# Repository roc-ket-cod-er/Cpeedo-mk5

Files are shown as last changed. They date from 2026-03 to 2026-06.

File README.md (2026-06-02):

# Cpeedo-mk5

>This project was funded by [Hack Club](https://hackclub.com/)'s Blueprint program. Hackclub is a registered, US based non-profit. Without their support, this project would not have been possible.

A _REALLY_ fancy bike speedo, designed in EasyEDA Pro and Fusion 360.



WIN_20260330_20_14_14_Pro

WIN_20260330_20_20_43_Pro

[DEMO!](https://www.youtube.com/watch/DLDQR-w_GeQ)

## Key Features

As the main goal is to measure speed, it obviously does so.

In addition, it also supports:
- a cell connection;
- anti-theft features, including using that cell connection to send the bike's position to the internet;
- a double LCD + bonus E-INK display, for live speed (etc) monitoring;
- two independent ways of measuring speed: a wheel rotation counter + GPS;
- an SD card;
- features for live navigation.

## PCB



> ⚠️ Render not up-to-date

The PCB has a 6-layer stackup to keep 2 solid ground planes, that is essential to keep the ground planes completely unbroken otherwise the antenna will be unhappy.

The stackup is:

1. Signals & Ground
2. Ground
3. Signals & Ground
4. Signals & Ground
5. Ground
6. Signals & Ground

### PCB Layers

Here's the PCB's Top layer (ground fill hidden)



Layer 3:



Layer 4:



And the bottom Layer (ground fill hidden)



> Remember, layers 2 & 5 are solid ground.

### PCB 3D Views:

Top: 



Bottom:



Bonus:



Bonus 2:



## Inspiration

Always, whenever I have been in motion, I have always wanted to know how fast I'm going. Like for some reason, you just expect to be able to know. And once you know, you can start racing yourself, start getting better, start pacing yourself, and just have more fun in general. I have made several previous editions, but in motion it has always been very hard to read the screens, and thus this time I have implemented an E-INK along with bright LCDs.

In addition, I have become increasingly paranoid about my bike being stolen, thus it would make ulitimate sense to achieve both things in one project.

## How to use

In this repository, you will find the files you need to print the case yourself, along side to get the PCB manufactured. The code, too, is present (but not finished). Thus, it is as simple as loading the code onto the board, and you should be good. The LCDs have ribbon cables, making the connection really easy, whilst the E-INK required the normal jumper wires to be hooked up.

Just put the screws into their holes, and behold! You shall have completed!

## Schematic

Here's the schematic in case you want to see it in PNG form!

SCH_Schematic1_1-Cellular_2026-02-10

SCH_Schematic1_2-GNSS - GPS_2026-02-10

SCH_Schematic1_3-STM32_2026-02-10

SCH_Schematic1_4-ESP32_2026-02-10

SCH_Schematic1_5-STM32_Sensors_2026-02-10

## BOM (PRICES MAY HAVE CHANGED: THIS IS FROM ~JAN 29 2026)

|Item |Cost (native) |Cost (USD)|Link |NOTE |TOTAL: |
|---|---|---|---|---|---|
|PCB |US$208.40+13%GST|$235.50 |JLCPCB.com |GST may not be collected. |$340.89|
|SIM card |CA$25 |$20.76 |simbase.com |Includes Adding Funds to the SIM. Taxes may reduce 13% | |
|Waveshare |US$62.47 |$62.47 |https://www.waveshare.com/catalog/product/view/id/6414/s/2.8inch-capacitive-touch-lcd/category/398/ and https://www.waveshare.com/2.9inch-e-paper-module.htm|Includes 2x LCD, + 1x E-INK + Shipping. Taxes may increase by 13%| |
|3D print |-- |$10.00 |Library |Estimate | |
|Screws |US$7.83+13% GST |$8.85 |https://www.aliexpress.com/item/1005005523283652.html |M2.5x8mm, 100pcs (minimum selected) | |
|Screw Head |US$2.94+13% GST |$3.32 |https://www.aliexpress.com/item/1005003319507557.html |T8 | |

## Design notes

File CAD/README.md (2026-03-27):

You'll find all the CAD files here.

<small> printer 1: +0.1mm 2: +0.3mm </small>

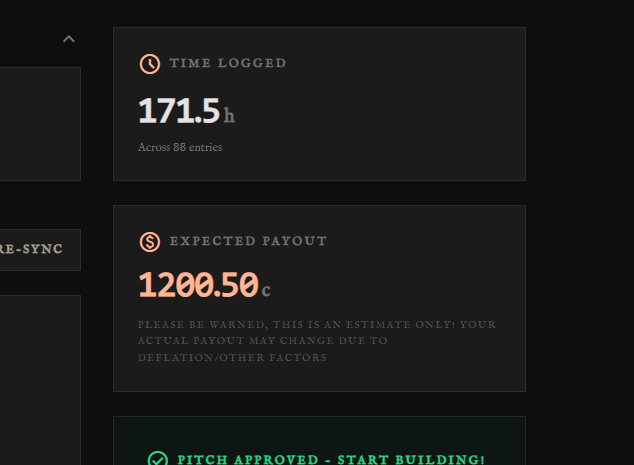
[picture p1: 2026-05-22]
assets/image.png

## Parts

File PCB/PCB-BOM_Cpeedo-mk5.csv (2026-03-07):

No. | Quantity | Comment | Designator | Footprint | Value | Manufacturer Part | Manufacturer | Supplier Part | Supplier
1 | 2 | BH-18650-A1AJ006 | BT1,BT2 | BAT-TH_BH-18650-A1AJ006 |  | BH-18650-A1AJ006 | MYOUNG(美阳) | C5290175 | LCSC
2 | 1 | 2.7pF | C1 | C0402 | 2.7pF | 0402CG2R7C500NT | FH(风华) | C1561 | LCSC
3 | 1 | 0.5pF | C2 | C0402 | 0.5pF | 0402CG0R5B500NT | FH(风华) | C285052 | LCSC
4 | 29 | 100nF | C3,C4,C5,C8,C10,C11,C12,C13,C14,C15,C20,C21,C31,C33,C34,C35,C38,C40,C41,C42,C43,C46,C52,C53,C54,C55,C57,C59,C60 | C0402 | 100nF | CL05B104KB54PNC | SAMSUNG(三星) | C307331 | LCSC
5 | 2 | 2.2uF | C6,C7 | C0603 | 2.2uF | CL10A225KO8NNNC | SAMSUNG(三星) | C23630 | LCSC
6 | 4 | 10uF | C9,C26,C27,C45 | C0603 | 10uF | CL10A106KP8NNNC | SAMSUNG(三星) | C19702 | LCSC
7 | 5 | 1uF | C16,C39,C49,C51,C56 | C0402 | 1uF | CL05A105KA5NQNC | SAMSUNG(三星) | C52923 | LCSC
8 | 4 | 100uF | C17,C18,C19,C32 | C1206 | 100uF | CL31A107MQHNNNE | SAMSUNG(三星) | C15008 | LCSC
9 | 2 | 10uF | C22,C36 | C0402 | 10uF | CL05A106MQ5NUNC | SAMSUNG(三星) | C15525 | LCSC
10 | 1 | 4.7uF | C23 | C0402 | 4.7uF | CL05A475MP5NRNC | SAMSUNG(三星) | C23733 | LCSC
11 | 2 | 15pF | C24,C25 | C0603 | 15pF | CL10C150JB8NNNC | SAMSUNG(三星) | C1644 | LCSC
12 | 5 | 22uF | C28,C29,C30,C37,C44 | C0603 | 22uF | CL10A226MQ8NRNC | SAMSUNG(三星) | C59461 | LCSC
13 | 1 | 2.2uF | C58 | C0402 | 2.2uF | CL05A225MQ5NSNC | SAMSUNG(三星) | C12530 | LCSC
14 | 1 | TF PUSH | CARD1 | TF-SMD_TF-PUSH |  | TF PUSH | SHOU HAN(首韩) | C393941 | LCSC
15 | 1 | SRV05-4 | D1 | SOT-23-6_L2.9-W1.6-P0.95-LS2.8-BL-1 |  | SRV05-4 | R+O(宏嘉诚) | C7420376 | LCSC
16 | 1 | PZ254V-11-05P | H2 | HDR-TH_5P-P2.54-V-M |  | PZ254V-11-05P | XFCN(兴飞) | C492404 | LCSC
17 | 3 | AFC07-S18FCC-00 | JP1,JP2,JP3 | FPC-SMD_AFC07-S18FCC-00 |  | AFC07-S18FCC-00 | JS(钜硕电子) | C11054 | LCSC
18 | 1 | 1462000001 | L1 | ANT-SMD_L40.0-W5.0_1462000001 |  | 1462000001 | MOLEX | C3284456 | LCSC
19 | 1 | 7.5nH | L2 | IND-SMD_L1.2-W0.6 | 7.5nH | SCW1005C7N5JST | Sunltech(顺磁) | C330848 | LCSC
20 | 1 | 2.2uH | L4 | L1008 | 2.2uH | DFE252010F-2R2M=P2 | muRata(村田) | C488330 | LCSC
21 | 2 | BLM15AX102SN1D | L5,L6 | L0402 |  | BLM15AX102SN1D | muRata(村田) | C85815 | LCSC
22 | 1 | KT-0603R | LED1 | LED0603-RD |  | KT-0603R | KENTO | C2286 | LCSC
23 | 3 | KT-0805G | LED3,LED4,LED5 | LED0805-R-RD |  | KT-0805G | KENTO | C2297 | LCSC
24 | 3 | BSS138 | Q1,Q2,Q3 | SOT-23-3_L2.9-W1.6-P1.90-LS2.8-BR |  | BSS138 | onsemi(安森美) | C52895 | LCSC
25 | 3 | 22Ω | R1,R2,R3 | R0402 | 22Ω | 0402WGF220JTCE | UNI-ROYAL(厚声) | C25092 | LCSC
26 | 4 | 5.1kΩ | R6,R7,R8,R9 | R0402 | 5.1kΩ | 0402WGF5101TCE | UNI-ROYAL(厚声) | C25905 | LCSC
27 | 16 | 10kΩ | R11,R14,R17,R25,R26,R27,R28,R29,R30,R31,R32,R33,R34,R35,R36,R44 | R0402 | 10kΩ | 0402WGF1002TCE | UNI-ROYAL(厚声) | C25744 | LCSC
28 | 7 | 680Ω | R12,R13,R15,R16,R18,R41,R42 | R0603 | 680Ω | 0603WAF6800T5E | UNI-ROYAL(厚声) | C23228 | LCSC
29 | 1 | 1kΩ | R19 | R0603 | 1kΩ | 0603WAF1001T5E | UNI-ROYAL(厚声) | C21190 | LCSC
30 | 1 | 100kΩ | R20 | R0402 | 100kΩ | 0402WGF1003TCE | UNI-ROYAL(厚声) | C25741 | LCSC
31 | 1 | 33Ω | R37 | R0402 | 33Ω | 0402WGF330JTCE | UNI-ROYAL(厚声) | C25105 | LCSC
32 | 1 | 36.5kΩ | R38 | R0603 | 36.5kΩ | 0603WAF3652T5E | UNI-ROYAL(厚声) | C23029 | LCSC
33 | 1 | 20mΩ | R43 | RES-SMD_L6.4-W3.2-R2512 | 20mΩ | RE2512F3R020 | JIERR(捷而瑞) | C46961755 | LCSC
34 | 4 | TS-1088-AR02016 | SW1,SW2,SW3,SW4 | SW-SMD_L3.9-W3.0-P4.45 |  | TS-1088-AR02016 | XUNPU(讯普) | C720477 | LCSC
35 | 1 | SK12D07VG4 | SW5 | SW-TH_SK12D07VG4-1 |  | SK12D07VG4 | HanElectricity(瀚源) | C22435621 | LCSC
36 | 1 | K3-1204D | SW6 | SW-TH_K3-1204D |  | K3-1204D | 韩国韩荣 | C145861 | LCSC
37 | 1 | SIM7080G | U1 | LCC-SMD_SIM7080G |  | SIM7080G | SIMCOM(芯讯通无线科技) | C2943992 | LCSC
38 | 1 | NANO SIM XG6P H1.35 | U2 | SIM-SMD_NANO-SIM-XG6P-H1.35 |  | NANO SIM XG6P H1.35 | SHOU HAN(首韩) | C7529386 | LCSC
39 | 1 | STM32U575VGT6 | U3 | LQFP-100_L14.0-W14.0-P0.50-LS16.0-BL |  | STM32U575VGT6 | ST(意法半导体) | C5270988 | LCSC
40 | 1 | ESP32-S3-WROOM-1-N16R8 | U4 | WIRELM-SMD_ESP32-S3-WROOM-1 |  | ESP32-S3-WROOM-1-N16R8 | ESPRESSIF(乐鑫) | C2913202 | LCSC
41 | 1 | TXB0108RGYR | U5 | VQFN-20_L4.5-W3.5-P0.50-BL-EP |  | TXB0108RGYR | TI(德州仪器) | C194701 | LCSC
42 | 1 | L80RE-M37 | U6 | GPSM-SMD_12P-L16.0-W16.0-P2.54-BL |  | L80RE-M37 | Quectel(移远) | C3029061 | LCSC
43 | 1 | ABM8-272-T3 | U7 | CRYSTAL-SMD_4P-L3.2-W2.5-BL |  | ABM8-272-T3 | ABRACON | C20625731 | LCSC
44 | 1 | TPS63021DSJR | U8 | VSON-14_L4.0-W3.0-P0.50-BL-EP_TI_DSJ |  | TPS63021DSJR | TI(德州仪器) | C202140 | LCSC
45 | 1 | 1.5uH | U9 | IND-SMD_L3.0-W3.0_FTC303020D | 1.5uH | FTC303020D1R5MBCA | cjiang(长江微电) | C7423317 | LCSC
46 | 1 | INA226AIDGSR | U10 | MSOP-10_L3.0-W3.0-P0.50-LS5.0-BL |  | INA226AIDGSR | TI(德州仪器) | C49851 | LCSC
47 | 1 | TPS63900DSKR | U11 | WSON-10_L2.5-W2.5-W0.50-TL-EP |  | TPS63900DSKR | TI(德州仪器) | C1518762 | LCSC
48 | 1 | ICM-42688-PC | U12 | LGA-14_L3.0-W2.5-P0.50-TL |  | ICM-42688-PC | Tokmas(托克马斯) | C48586483 | LCSC
49 | 1 | BMM150 | U13 | WLCSP-12_L1.6-W1.6_BMM150 |  | BMM150 | Bosch(博世) | C171681 | LCSC
50 | 1 | 2541WR-08P | U16 | HDR-TH_8P-P2.54-H-M-W10.4 |  | 2541WR-08P | HanElectricity(瀚源) | C5383100 | LCSC
51 | 2 | KF350R-3.5-2P | U17,U19 | CONN-TH_P3.50_KF396R-3.5-2P |  | KF350R-3.5-2P | KEFA(科发) | C474896 | LCSC
52 | 1 | KF350R-3.5-3P | U18 | CONN-TH_3P-P3.50_KF396R-3.5-3P |  | KF350R-3.5-3P | KEFA(科发) | C474897 | LCSC
53 | 2 | TYPE-C 16PIN 2MD(073) | USB1,USB2 | USB-C-SMD_TYPE-C-6PIN-2MD-073 |  | TYPE-C 16PIN 2MD(073) | SHOU HAN(首韩) | C2765186 | LCSC

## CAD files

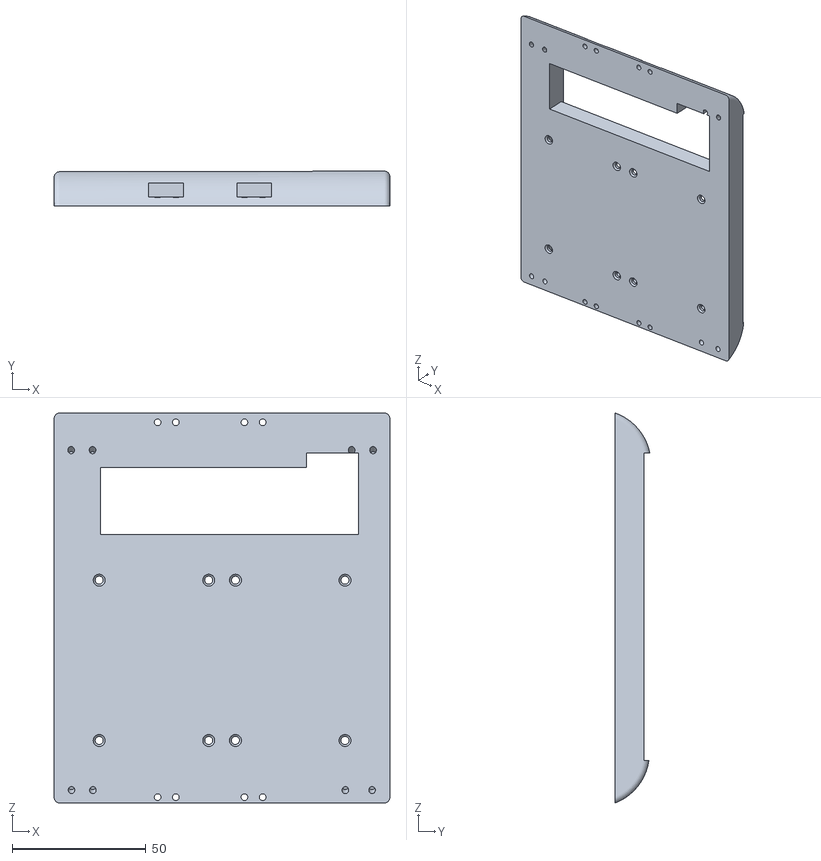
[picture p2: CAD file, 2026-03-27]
CAD/Main Truss.stl
125.7 x 13.0 x 146.0

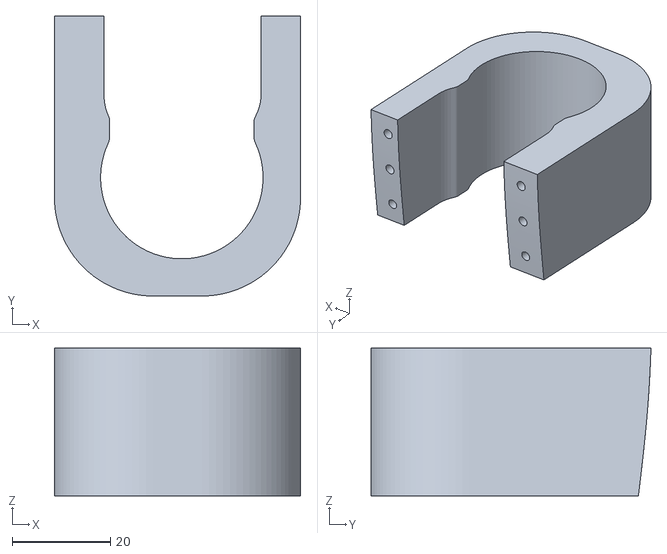
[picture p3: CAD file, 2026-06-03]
CAD/Bike-Mount.stl
50.0 x 56.9 x 30.0

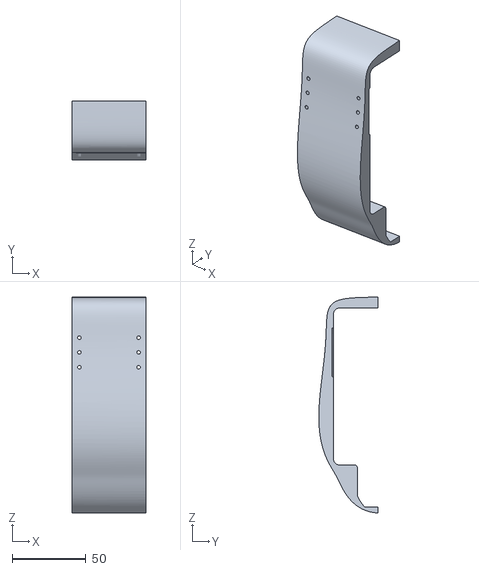
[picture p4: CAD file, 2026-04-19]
CAD/Battery.stl
50.0 x 40.1 x 146.0

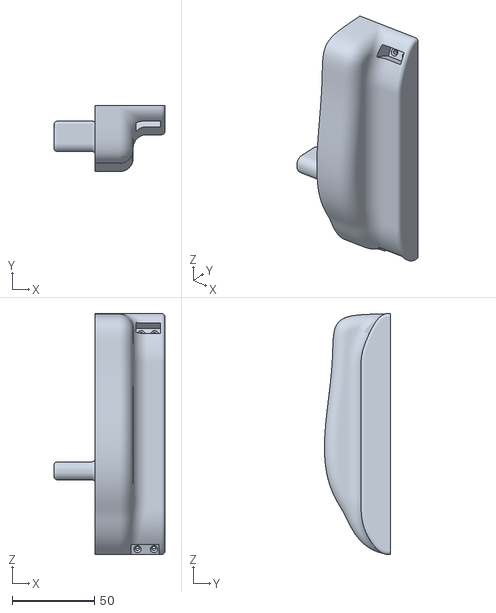
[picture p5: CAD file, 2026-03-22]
CAD/Right-Bottom.stl
67.3 x 40.1 x 146.1

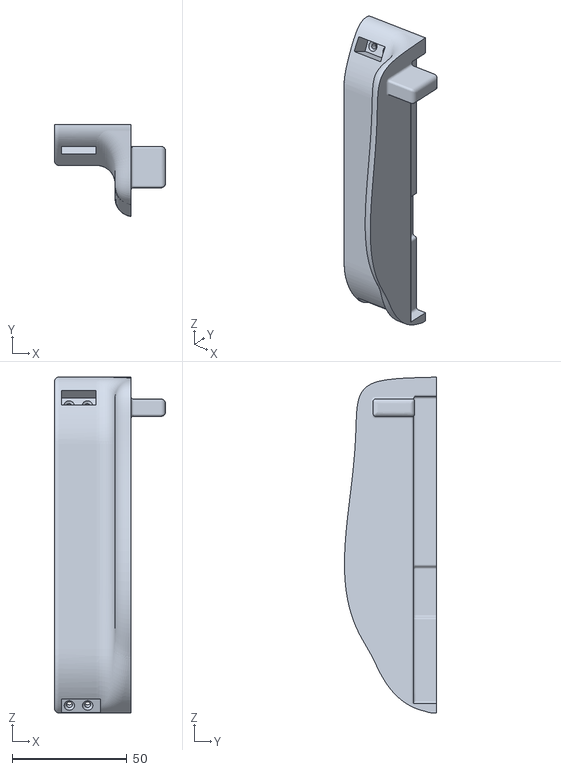
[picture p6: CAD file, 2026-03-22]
CAD/Left-Bottom.stl
48.4 x 40.0 x 146.1

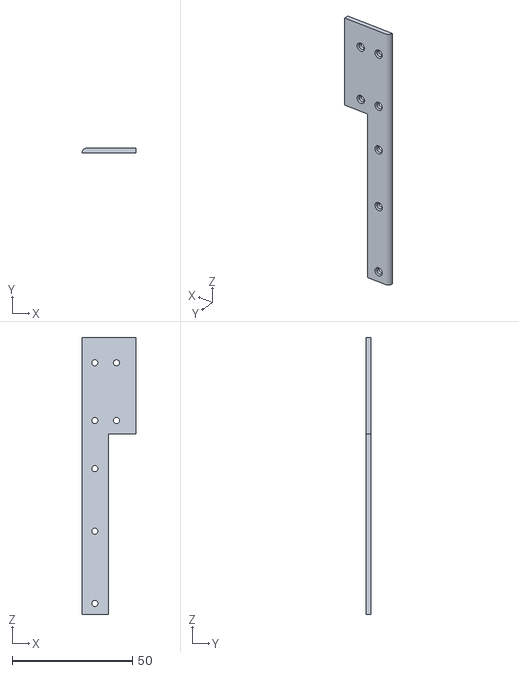
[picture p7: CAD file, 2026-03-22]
CAD/Left Mount.stl
22.5 x 2.00 x 115.1

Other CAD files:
CAD/Cpeedo-mk5.step
CAD/Right Mount.stl
CAD/Cpeedo-mk5.f3z

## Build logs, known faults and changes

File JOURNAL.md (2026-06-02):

---
title: "The Ultimate Bike Odometer"
author: "Madhav Garg"
description: "The best bike odometer you'll ever see"
created_at: "2026-02-20"
---

<!--
  This journal is auto generated by Hack Club Blueprint.
-->

# 2/25/2026 - Bought some stuff & checks and stuff  

_Time spent: 0.6h_  

Mostly just double-triple checked stuff and bought it!



So yeah, the thing is that one of the things was from a blocked category, so I had like get @jay to unblock it, but then he had to re block it, but the problem was I had 2 orders, so he had to do that twice...

Well anyways I probably did some other stuff but I forgot it all so...  

# 2/27/2026 6 PM - Rerouted a bunch of the bottom layer  

_Time spent: 1.9h_  

Basically, I want to put art onto the bottom layer, and thus I rerouted many signals so that the bottom is just mostly ground, on which its far safer to remove the soldermask



As you can see, there's only a bit of routing on the densest part of the board, but other than that its all gone!



Now time to actually get the art going!

By the way, most places were relatively easy, just switching the trace layer, but others required quite a bit of change.



I also tidied up this corridor so that the majority is in line with itself and thus doesn't affect the ground stitching around the ground plane too much.  

# 2/27/2026 9:36 PM - Artwork  

_Time spent: 0.7h_  

I added a bunch of new art, fully custom (except for the hackclub logo)

It took soooo long because in the beginning I was going to make a single PNG and import it, but I just ended up importing individual files and putting them in the right spot. It was just too hard to have one.





I'm going to clean up the backside a bit, but first I have to move all the Part-Identifiers so they are legible over this new silkscreen



# 2/27/2026 9:55 PM - Designators  

_Time spent: 0.4h_  

I moved all the designators on the top side so that they are readable with the new wavy lines. The backside will be done tomorrow, when I redo that silkscreen to not conflict with the hackclub logo.



Anyways, there just was this one spot with the microSD card where it was tough, but most of the other places were easy enough



# 3/2/2026 - Artwork & Suture/Stiching Vias  

_Time spent: 2.6h_  



First things first, I quickly fixed the artwork on the back side so that the hackclub logo wouldn't have lines going through it



However, on the front side I got feed back that the silkscreen was just a bit too much, especially with the ENIG art, and thus I removed it, even though I had moved all the designators...



 ### The hard part

So that was all good, just a bit of easy artwork. But, the stiching vias were _really_ bad this time, as for some reason the DRC was allowing the vias to be placed too close to each other, and then flagging them. So, I had to go through and remove each violating via by hand... (Some 50~60 vias)



> <small> btw my board now has 3000+ vias!! </small>

Anyways, after that, there was the headers for the speed and 2 IO (buttons, etc) that were sort of conflicting with the battery, so I re-arranged them.



 ### Debug Header

Reddit said that I should add the NRST pin broken out on the debug header, so that's what I did.



Required some wiring, including some on the bottom layer. (Which is my mostly empty one)  

# 3/3/2026 - Added Another FPC Connector  

_Time spent: 4.3h_  

This is basically just so that if in the future I want to have it connect to a daughter board, it will be able actually communicate. Because I didn't have access to STM32CUBEMX, I had to look through the datasheet to find out which pins (of the remaining) were the most capable so that I could actually use them. I settled on this setup:



> Note: STM/ESP32_SCK is actually PA1

So now, I was left with the daunting task of finding the ideal order (shown above) so that it would actually be possible to route. On my 5th revision, I found that.

---

Now to actually wire this monster up



As you can see, the majority of the lines look alr, and I might actually just change the two weird ones (on the bottom).

The biggest problem, however, is the fact that this is already the most dense part of the board, where the four layers are most full, so wiring an addition ~16 lines is not going to be fun. Thankfully, if absolutely need be, I can always use inner 4, which is supposed to be GND only...

 #### Some Time Later

Ok! I think I've settled on this setup for the pins:





Now time to route this all...

 ### ~~Routing~~ More double checking!

Here's (hopefully) the final thing.





_Now_ it's time for some routing

 ### Routing

(some time later)

Ok so here's what I have!



This is one heck of a dense board, with all four layers being quite well used: (L3,L4,L6)







Not gonna lie, but that was quite a bit easier than I was expecting. I did end up changing a bit of the schematic, so that it would actually be nicely usable, so here it is!



(Mostly just switching around a few pins to avoid loops)

Yeah well that was a full days work! Proud of what I got done.

Oh yeah, btw re-added the suture vias (the ones that connect between layers)

~~ALSO I NOTICED THAT ALL MY JOURNALS FROM THE PAST DAY ARE ALL GONE?????????????????????????????? Like 10 hrs of work dissapeared!!~~ Just a glitch  

# 3/4/2026 - Tested (& Received) E-INK DISPLAY!!!  

_Time spent: 2.3h_  

Firstly, I received the displays!!!!!

WIN_20260304_18_15_56_ProWIN_20260304_18_15_49_ProWIN_20260304_18_15_42_ProWIN_20260304_18_15_53_Pro

WIN_20260304_18_10_47_Pro

That last one might have looked weird ... that's my E-INK!

It was actually a pain to get it working. First, I connected it to my rpi Pico's wrong 3V3, so it wasn't getting power, then [the library](https://github.com/rdagger/MicroPython-2.9-inch-ePaper-Library/tree/master) was really weird and glitching out. So, I changed my library to Waveshare's official one, however I messed up and installed the 2.13 inch display one, not the [2.9 inch one](https://github.com/waveshareteam/Pico_ePaper_Code/blob/main/python/Pico_ePaper-2.9.py), so again it didn't work.

In between, I had messed up with which pins were SCK and MOSI, and kept getting the `Bad Pin` error, so that definitely wasn't nice.

All in all, it's really great it worked, but it took too much effort ... Hoping the LCDs are easier!  

# 3/10/2026 - LCD & E-INKing  

_Time spent: 4.5h_  

Alr, so, believe it or not, the LCD just worked first try!!!!!!

It was lowk so easy, took like 10 mins to wire it up (and double check and stuff) then I just found the official code and it just worked!!

While I'm at it, the screws also arrived, and hey, they fit!

And now the really time consuming part. E-INK custom text scaling!

WIN_20260308_16_11_53_Pro

Just so you know, I did, in fact, get it to work, but the thing is I just thought it would be as simple as just copying the LCD text scaler function over, and it would just work.

ye ofc it wasn't

But first, before I get to that part, I just wanted to talk about how I really goofed up in reading the E-INK code, so previously it would just drive the E-INK when the `vertical_write()` calls would come in, and not for the `horizontal_write()`, and I was really wondering why, and it turns out that I didn't change the SPI pins on the `Horizontal` class, just on the `Vertical` class.

Quick fix, just changed that, (but not so quick to find it, ofc) and now instead of waiting 10+ seconds for the screen to initialize, it just does so within a second!

So yeah, now that I had got that to initialize far faster (a problem I had been observing for quite a while, but was unsure of why), I decided that if my speedo was gonna be readable in bright sunlight, it would make most sense for the E-INK to be able to display speed, too.

Since, I needed it to be visible at a bit of a distance while shaking, I decided that I should find out how to make the text big enough to be readable. Hence, the problem

So I briefly touched upon how the LCD has a scaler, which it does, but the thing is that it's designed for a different setup, with colour displays and stuff.

So, I went looking online and I found [this.](https://github.com/orgs/micropython/discussions/16382)

Basically, it does the exact same thing, but somehow works (after much modding)

"What modding," you ask?

Well firstly, I had to actually _understand_ the code, and here's a rundown of what it does.

Put simply, it take micropython's framebuffer's built in font, and then reads it, by putting it into a new framebuffer and reading every pixel.

Then, it takes those readings, and draws rectangles that are the scale. So, if we were drawing to a 2x scale, it would draw the rectangles to be 2x2 pixels, instead of the default 1.

However, to do that, you must actually first make the framebuffer, which apparently can just be done by this:

>me forgetting and searching my code

ok so yeah its actually really simple, just go 

`temp_fb = framebuf.FrameBuffer(temp_buf, width, height, framebuf.MONO_VLSB)`

>(if you have imported the frambuf library)

The problem just was that the code there used something different, and I have basically never used framebuf.

Alright so once that is there, there is still the fact that normally, 0x00 is black, and 0xff is white right?

Well for some reason that was flipped

I was writing 0x00, and I was getting white, while 0xff was giving me black...

(I now know that that was just because of the fact that the temporary framebuf [the one with the micropython default fonts] was the right one, but then it was being flipped by a stupid piece of [my own] code.)

By the way, writing these huge essays takes sooo long



Anyways, yeah that's about it! Now I have the text scaler!

Also, there is this really stupid thing that even if I clear the buffer, running `buffer.Clear(0xff)`, it doesn't really, and I still have to run `buffer.fill(0xff)`

Oh well, also two more notes:

1. THE PCB IS DONE PRODUCTION!!! (Now all I have to do is wait for them to assemble it!)
2. I noticed that I can arrange the screens in a better way that should look better, And thus I'm thinking of completely remodling my entire thing... I should get that done real quick so that its done by the time the PCB arrives and I can just go print it and worry about debugging my PCB

 ### NOTE: As you can see, this is a really long journal, and really long journals take a tonne of time to get done on their own ...  

# 3/11/2026 - Re-3D modelling  

_Time spent: 2.0h_  

I finally came around to do it, and so here it is!

Not nearly (or even close to being) done...







So yeah, white is e-ink, screens are obviously screens, pcb is also obviously the PCB, and the beige is the main case. The orange is the mounting pieces that are going to be used to mount the E-INK on, as it doesn't have useful screw holes.

However, it does have a pin header, that has this hole for it:



(The center is also shallower as there is the E-INK driving circuitry on the back)

Not much more to say, other then the fact that I'm worried about the GPS performance, as it has the batteries right under it, even though there is supposed to be a keepout. In addition, the E-INK is also quite close to it, but I think it should most likely be alright.

I'm really proud of the fact that I was able to finish this so quickly, taking just about two hours.

Next time, my plan is to add the main PCB mount, and bother with the screws.

I also will have to figure out the bike mount clips, but I think I'll do that part and the battery mount section later, after I get this part printed out and tested.  

# 3/13/2026 - Pretty Much Finished 3D Model  

_Time spent: 4.5h_  

So yeah, I Pretty Much Finished 3D Model.



All I really need to add know is the bike mount, and the screw holes to hold everything together!

So, pretty much, all I worked on was the back part.



This part will hold the PCB, in such a way that, with screw holes, will be able to also accommodated the batteries in a way that they can be removed for charging.



Where the more turquoise blue is is where the batteries are, and that is also where the thing will come off for when I want to recharge the batteries.

This might not seem like a lot, but compared to my last render, this whole workflow just _happened_ much faster, and I'm actually quite proud.

And this is even after me having to redo much of my work, as V18 got deleted, so I had to go back to V17, and there was this problem:



Even though it's just the inside, I wanted that to also look nice, so that's why I wanted to fix that up, but the normal way I would do it in fusion 360 didn't quite work as it would keep say computation error. Thus, I had to go google it, and it wasn't of much help either. So, I just tended up deleting that bad part, and just extending the sides all the way to the cover that area.





Here's what the inside looks like:



Again, where its more turquoise is the battery area, whereas the bluer area is the other mounting part.

Just reworked some stuff for tolerances, so here it is:

PCB CASE:







FULL:







# 3/14/2026 - Worked On 3D Model: Bike Mount  

_Time spent: 1.8h_  

I speedran the bike mount, the place where the speedo will mount to the bike



This is my first try at clip-on 3D prints, as the hole is a millimetre or two too small, so it's gonna be under a nice amount of pressure and thus gonna have a tonne of friction.





It's also designed to be screwed on right here to connect to the main body.

It should be noted that everything is a touch too small to make sure there is sufficient friction.

It is also nice that the bar is vertical,



So that the friction only has to prevent it from rotating sideways, not up and down.

I'm still a bit confused on how to connect it and everything, but its gonna probably be that the mount screws onto the back battery plate, which then has screws to the main body that are gonna have to be taken off everytime the batteries need to be charged.

Now all I need to do is add the screw holes, and I should be done!  

# 3/15/2026 - Added:   S O   M A N Y   S C R E W   H O L E S  

_Time spent: 3.7h_  

yep, that's what I did.

 ### Firstly, there is the top side:



A _TONNNE_ of screw holes. It should be noted that the screw hold on the right side, bottom left of the box, is just there for show.

There is nothing for it to dig into.



 ### Back Side:

Here it is:





This all required me to cut out the bottom plate so that the screws can fit, as there is really only one screw type that is going to be used in all the holes.

 ### The hard part: PCB Mount

When looking here, its hard to see:



But if I hide the PCB:



Not only did the hole alignment take so long, but also the fillets took just s o . l o n g .

s o o o o o o o o o . l o n g .

They kept on giving me errors, and all that nonsense. At least I didn't have to chamfer these holes.

 ### Chamfering

If you looked really closely, you'd see the chamfering:



This is so that the screw can sit flat, and this too took so long, as google just couldn't tell me how to chamfer. (It was really simple once I found it)

Now all I need to do is the back mount!



PCB should be arriving tomorow!

bonus:

(main truss, looks so tuff)









# 3/16/2026 - PCBs ARRIVED: GOT THE LED TO BLINK!!!!!  

_Time spent: 1.7h_  

Yep. Believe it or not, the naysayers and the haters have been shut down for good.

Those little-lings will now not be able to call me "one-who-cannot-program-an-stm32" as that is just what I did.

So it was a real mess trying to get everything to work, but really all I had to do was just ask @tty7 to tell me why it wasn't working, and all he had to do was tell me that you actually have to press the "boot" button for picky Ms. Windows to detect the STM32.

From there it was ~~smooth sailing!~~ more pain...

So now I had to figure out how to program it. @tty7 wasn't gonna be available for an hour, so instead I spent that hour in the googles. Firstly, I looked for a way to program it. Arduino IDE maybe? yeah no that didn't work

So I came back and found [this epic video detailing exactly how to program the STM32 by USB](https://www.youtube.com/watch?v=VlCYI2U-qyM)

and From _there_ it was ~~smooth sailing!~~ more pain...

yeah this time I had to like actually find out how the main things work, and considering the include the `main()` functions box was unchecked, that must have been a real nice, easy, time.

So once I rechecked that box, added these two lines of code:



and then flashed it like how the video said, and it just worked!

Lowk so happy

oh yeah forgot to say, my PCBs ARRIVED!!!!!

lowk so cool. I need to solder the ESP32 on, find libraries for my stuff and maybe not even use this, repent for making a _micropython_ library for text scaling, and yeah.

Also, I'm paranoid I'm going to plug the battery in the wrong way and cook my stuff, so there's that. Haven't yet soldered on the battery holder, so once in a while power just cuts out. (the USBs don't provide my board with power)  

# 3/18/2026 - Got CELL TO WORK & soldered esp32  

_Time spent: 7.8h_  

Most importantly, I got the CELL STUFF TO WORK!!!



But anyways, the story

 ### Soldering

Firstly, there was the soldering.

Preparations alone took me like 30~45 minutes, as I had to find a space, clear it, and then the difficult part: find the components.

So, the thing is, the ESP32s sort of disappeared, but were actually where I though they were all along, so minus 10 minutes (yes, I know, I'm slow)

Then, the same thing happened with the Flux. Like it shouldn't be so hard to find a big tube of orange goo, when I don't own anything orange.

<small>
>(idk where it was now, and i lowk managed to lose it _again_ ... nvm found it)
</small>

Anyways, then the flux tube wouldn't open.

At first, I thought that I stored it wrong or something, but no it was alright. So then _why would it not just open_?

because it was too cold

All I had to do was just add some heat, and voila it just opened

THEN, on the first board I guess I messed up and put too little flux or something, but when I soldered the ESP32, it just didn't go very well, and uhh i also tried pre-adding solder to the pads and that ended up just desoldering the decoupling capacitors.



Thankfully, the second set of stuff went much easier, and I just powered it and connected it and it just worked!!!!

The default firmware on these chips is cooked, so that's why I had to quickly flash new firmware before windows gave me a headache of complaints.

Alls well, though, and it just worked.

Next up, the switch.

 ### Stupid Switches

Don't you just love alliteration.

Anyways, normally, when you slide the switch to the right, the right and center short, whilst the left two are not. Right????????

Nope. Not on this switch. That took me _sooooo_ long to figure out why it wasn't getting power (the cell chip)

It took me so long to get the wits to actually bother to check the resistance and its behaviour... :(

Well, whatever, it works it works.

 ### Coding & Cell

Ok, now the sad part.

When I was testing the stuff for voltage, I accidentally shorted the outside of the antenna to the VBAT pin, and who would think, the outside is connected to GROUND.

So well, what happens when you short the pins like that? Smoke. Lots of it. Well I was about to give up at that, but I thought: "hmmmm what if I try and plug it in anyways?"

So I did.

Plugged the battery in, and the STM32 turned on (it was programmed just to blink its LED)

Turned on the switch for the ESP32. 

And.

IT ALSO TURNED ON!!!!

So basically, as far as I could tell, all was well.

But there was still the CELL CHIP. I knew for a fact that it was a very sensitive chip, so I was just given up on that and willing to accept a functional ESP32/STM32 devboard.

So, when I first failed to turn on the Cell Chip, I was sort of just confirming my suspicion. But, against all odds (after 30+ minutes) I decided to consult chatGPT.

I don't normally ever use it, as it hallucinates random code more often than useful code.

But it actually worked.



<small> my shock ^^^ </small>

Anyways, that was absolutely great news. Despite smoke coming from my board, it just worked.

Then, I just fumbled with chatGPT to give me AT commands, and it, again, just worked.



However, there was this small problem. I was getting signals once in a while. However, thankfully, it was just warming up, and now it connects reliably.

The next problem was actually getting Adafruit IO to receive data, and that was done by just taking a look at what AT commands Waveshare uses on there SIM7080G boards, and copying them. (More like adapting them to my framework, as they were written for the Raspberry Pi)

And yeah, in short, that's all I had to do. I sort of glazed over the _hours_ of pain that it took to get it working with the SIM module, but hey, all's well that ends well.

I also had the horrifying thought of giving up hardware. Super happy I didn't!!  

# 3/20/2026 - Cleaning Up Basic Code & HTTP SADNESS  

_Time spent: 5.1h_  

So I spent an hour or two cleaning up my code, so basically it's like _clean_ and working well.

Whereas my previous code was comprised of functions and AT commands every where, my current setup is having a proper function, with some comments, but not very many.

```python
def connect_to_cell(server, url=''):
    global connected
    if not powered_on():
        power_on()
    
    send_at('AT+SMDISC') #DISCONNECT FROM ADAFRUIT IO
    send_at('AT+SHDISC')  #DISCONNECT FROM HTTP
    
    #send_at('AT+CGDCONT=1,"IP","simbase"')
    
    while "99,99" in send_at("AT+CSQ", wait=.1):		# signal
        sleep(0.3)=

    while "NO SERVICE" in send_at("AT+CPSI?", wait=.1):
        send_at("AT+CSQ", wait=.1)
        sleep(0.3)

    send_at("AT+CGACT?", wait=.1)		#active?
    send_at('AT+CGDCONT?', wait=.1)		#ip & stuff
    send_at('AT+CGPADDR=1', wait=.1)		#connect to wifi
    
    send_at('AT+CNACT=0,1', wait=.1)
    send_at('AT+CACID=0', wait=.1)

    if server in ['io', 'adafruit', 'mqtt']:
        send_at('AT+SMCONF="URL","io.adafruit.com",1883', wait=.1)
        send_at('AT+SMCONF="CLIENTID","esp32-sim7080g"', wait=.1)
        send_at('AT+SMCONF="USERNAME","space_coder"', wait=.1)
        send_at('AT+SMCONF="PASSWORD","WHY THE HECK ARE YOU TRYING TO SEE MY PASSWORD????????"', wait=.1)
        send_at('AT+SMCONN', 1)
    if server in 'https':
        send_at('AT+SHCONF="BODYLEN",1024', wait=.1)
        send_at('AT+SHCONF="HEADERLEN",350', wait=.1)
        send_at(f'AT+SHCONF="URL","{url}"', wait=.1)
        send_at('AT+SHCONN', 5)

    connected = True
```

(cleaned up version)

That, above, is my connect function, and as you can see in addition to cleaning up the code, I also figured out how to speed it up so that it works well. Whereas my previous function would take well over 15 seconds, some two seconds per command, now it takes about 3 seconds to connect to Adafruit IO, or about 7 seconds to connect to connect to a webpage (I'll get to this later).

I also set it up with the DTS and RTS commands, so that if I want higher bauds, in the MHz range, I can.

Furthermore, I re-setup the UART, as previously there was a built in slowing function, adding about 1 second to every read.

 ### HTTPS

~~So this part was just like the others~~

I wish.

The other cell features were actually pretty easy, but this time chatGPT started overly hallucinating, so that is why it took _so_ long.

Firstly, there was the pinging. To get it to send a ping, I had to find a good source, as GPT wasn't working. [This one](https://onomondo.com/blog/how-to-ping-your-modem-using-at-commands/) had a good chunk of the stuff I needed, but it was a bit confusing, as the APN was different on their page. All in all, the pings were quite easy, and then there was the actual reading part.

Reading is as simple as sending `send_at('AT+SHREQ="/",1', 10)` and then `send_at('AT+SHREAD=0,528', 10)`

But the connection part is a whole other mess.

So as you can see, my current connection function asks whether I want to connect to IO or HTTP, and that's not because of speed or anything. That's because 90% of the time it cannot connect to both. So the correct course of action would have been to disconnect from the IO, as I now do, and then connect to the HTTP, however I didn't know that, so I was just like stuck and wondering why my connection code wasn't working, but the example did.

Once I figured that out, it was quite easy, really. Just make sure to disconnect, and all should be well.

 ### The Pain

So, I decided that I was going to clump the functions and clean them up so that it won't waste time and data connecting to the MQTT if I wanted the HTTP, and vice versa. So, I put the code in and it just didn't work. I debugged it for a solid _hour_ and I finally found the problem. I had commented out the lines of code that told my modem how much of a buffer to assign to the read function, and voilà, nono functioning.


Uncommenting those lines pretty much fixed the entire problem, and yeah.

 ### 3D printing

I went to the library today to see if they had a printer open, and, even in this weather (its raining/cold), there was not a printer (out of 2) that was open.

Also, I'd just like to note: picture are going to be hard as I don't have much to show, other than code, and I don't have a camera.

<small> p.s. This journal alone took me 17 minutes of locking in/focusing.  

# 3/21/2026 8 PM - Finished 3D Model  

_Time spent: 2.0h_  

Yep!

I fixed up tolerances, and added the final screw holes!




That means 6 holes here (3 both sides)


which connect to the battery clip here:





Which connects to the body here:






This side didn't have enough space, so the chamfer and screw hole actually goes a bit onto the sides:





I also fixed up the display holes so that they would actually hold the screw, and not just let it slide right through.

  

# 3/21/2026 9 PM - Got 2x 3D printed parts  

_Time spent: 0.1h_  

I went to the library and just sat there for ~30 mins waiting for my print. Gonna have a lot more of that...

Anyways, I just barely missed my bus home, so I had to wait an extra 30 mins :(

WIN_20260321_21_58_30_Pro

I'm not adding the 2hrs.  

# 3/21/2026 10 PM - Got Screens To Work  

_Time spent: 1.8h_  

So yeah, basically I got them to work!

WIN_20260321_21_50_21_ProWIN_20260321_21_50_15_Pro
WIN_20260321_21_50_29_Pro
WIN_20260321_21_50_35_Pro

So, I had already got the screen to work, but that was by connecting them to my rpi Pico, which apparently has more RAM than my ESP32 (not PSRAM, RAM)

So I got this lovely error:

```
MemoryError: memory allocation failed, allocating 153600 bytes
```

 ### New Library

Ok, well the official waveshare one didn't work, so I thought of just googling the chip, the ST7789T3. And right there, I found the [ST7789](https://github.com/russhughes/st7789_mpy) Library, something that I have even used before!

The thing is, I'd forgotten a bit how to use it, but mostly my brain was cooking, and I flashed the new micropython file and

...

...

LOST ALL MY FILES :(((

It wasn't that bad, as I had my main file backed up to my computer just in case, so thankfully, it's mostly all well. Just for my own stuff, I'll put it at the end of this journal too.

So, with this new (outdated) micropython file, I tested my original code, and there was just a tiny difference, with the way you assign pins for uart, but other than that all was well.

So that still wouldn't explain why it wasn't working.

Well, turns out, I wired my display connector wrong. What I put as pin 1 was actually 18, and vice versa all the way.

Thankfully, the geniuses at waveshare thought that someone might be that stupid, and thus they made their conector have contacts on both sides, so you can insert the cable either way, and swap it around so that all is well!

And after that, all went quite well.

Anyways, I'm a bit concerned about the amount of power the cell chip is drawing, as its quite a bit. In all of this testing, the voltage has dropped by ~0.3V (so maybe ~.1V per hour? I guess that's not terrible) from 4.008V to 3.758V

<small> I really wonder why I'm so slow at journalling: this one took me 15~20 minutes </small>  

# 3/22/2026 6 PM - Tried To Get Arduino IDE  

_Time spent: 1.3h_  

I know that all my previous journals always had stuff getting working, but this time it was very different.

Arduino IDE logged 40 minutes of me trying to get it to work, but if you include googling, cubeMX programming and all of that (not-so-fun) stuff, it was a bunch more.

Anyways, what I basically did was just spent my entire time seeing why my board wasn't showing up, while there were others, and I'm not even really understanding why, but my chip just isn't supported, so I'm going to have to use HAL and STM32CUBEMXIDE, which is even harder :(

lowk i just wish we could get micropython.

  

# 3/22/2026 9 PM - Got Two Screens to Work  

_Time spent: 0.5h_  

Spent a bit of time modifying the code to drive both screens simultaneously, and here's the result!

Only one minor hiccup, I accidentally defined two different SPI lines for each, using the same pins, and micropython didn't like that.WIN_20260322_19_37_43_ProWIN_20260322_19_37_41_ProWIN_20260322_19_37_37_ProWIN_20260322_19_37_42_ProWIN_20260322_19_37_41_Pro (2)WIN_20260322_19_37_39_Pro
WIN_20260322_19_37_49_Pro
WIN_20260322_19_37_50_Pro
WIN_20260322_19_37_44_ProWIN_20260322_19_37_30_Pro
WIN_20260322_19_37_52_Pro[WIN_20260322_19_50_41_Pro](/user-attachments/blobs/proxy/eyJfcmFpbHMiOnsiZGF0YSI6MTI1ODk1LCJwdXIiOiJibG9iX2lkIn19--d4184eec703dec77a4d681dd8b0ce64d7fdfb67c/WIN_20260322_19_50_41_Pro.mp4)

# 3/23/2026 - Worked on connection script optimisation  

_Time spent: 0.6h_  

I made a new connected function which basically uses AT commands to detect if its connected so it doesn't reconnect, unless the connect functions' `force=True` (default `False`)



I also implemented it, and also did a 70 minute test with a message outgoing every 2.3 seconds to Adafruit IO, and it ended up using about 200kb (for ~1700 messages)

Looks pretty good to me!

I also stated implementing the `show` flag, to hide outputs for useless commands, such as `AT+SMSTATE?` and `AT+SHSTATE?` as the connect function will handle and tell me what happens.  

# 3/27/2026 - 3D Model Fix & Coding  

_Time spent: 4.9h_  

So I got my parts, but as they required support material, they are all cooked. Well that was a nice quick fix, but I lost an hour or so in going to start the print and the getting them.

But I just realized, right as I'm writing, that I forgot to add a hole for the FFCs, and so I'm gonna have to route them in the most awkward weird way. I'll fix them in a later revision.

Since I have (most of) the parts, I can now see that this thing is gonna be quite fat, and fingers crossed it still looks alr.WIN_20260327_21_40_54_Pro
WIN_20260327_21_41_06_ProWIN_20260327_21_40_48_ProWIN_20260327_21_40_44_ProWIN_20260327_21_41_00_Pro

And after that I spent 3 and a half hours coding to make the text as big as you can see above.

This including learning how to make custom fonts.

The custom fonts were the hardest part.
The custom fonts were the most time consuming part.
The custom fonts were (pretty much) the only part.

Uhh no actual there was also one small other thing.

Anyways, here's my list of errors, after spending like an hour trying to force my brain to understand how the font generation works. By the way, it doesn't help that the docs and everything are pretty much non-existent and really old.

 ### #1 Wrong function: I used monofont2bitmap, which isn't compatible, whereas font2bitmap is. ????????

I still had to debug it to give me an output, which included installing a library, finding out it was too new and didn't have some functions, vibecoding a fix, and just wondering why????

In addition, its debugging was ... not so good?

Spent far too long trying to see why it kept giving a (seemingly) random error, and as it turns out, I needed the -c or -s flags to tell it which chars... WHY CAN'T IT AUTO DO THE ONES I NEEEDDDDD????????? :(

And after all that, I was wondering why the write function was failing. Firstly, it was because of using the wrong function (more later) and because this function gives an incompatible bitmap. How nice.

 ### #2 Right function, wrong writing method

So, I go in and use the `text` function, as I've always done, and it throws a random error. No clue why. ChatGPT gives me the right answer, but I thought it was hallucinating. So, digging through the very outdated docs, I actually find it! The correct function was the `write` one.

and that pretty much would have fixed it, if not for me being in the wrong file

 ### #3 Wrong File:

So like it should be really hard to edit the wrong file, right?

Well no. When you have two files, one for the old code and one for the new, that can happen. I used the `write` function with the in-built font (which requires `text`) and it didn't work.

How nice

Minus an hour (like 10 mins) of my life I will never get back.

So, once I find that out, I immideately rage-close the file, and well everything went nice afterwards.

I just spent a bunch of time getting the font size right, getting it centered and all that stuff, and getting 1 to become 01, etc.

Well I probably forgot smth, but that should be the gist of it!  

# 3/28/2026 6 PM - Threaded Holes  

_Time spent: 2.0h_  

Well that was a lot of holes. I ran the screws in the holes to thread them. For the holes that were not so usable, I first drilled out the support material, and _then_ threaded them.

I also mounted the screens onto the main trus, but I have a problem that the holes are all too big on the main truss, and thus its basically impossible to keep the e-ink on, but I don't quite have enough time to fix it, so ig it'll just have to work for now. I'm going to get the last parts today, (if they didn't fail) and I'll thread them and everything for tomorrow so I can go test it!

I'll just quickly ( ** hopes ** ) finish them off.

I keep forgetting to get receipts, so the majority of the prints are coming out of my money. Already burnt through $10.

WIN_20260328_18_09_03_Pro
WIN_20260328_18_09_13_Pro

# 3/28/2026 10 PM - Software and assembly  

_Time spent: 4.0h_  

I got the rest of the components!

After removing supports, here is the structure!

WIN_20260328_22_29_52_Pro
WIN_20260328_22_30_29_Pro
WIN_20260328_22_30_38_ProWIN_20260328_22_27_27_ProWIN_20260328_22_27_21_ProWIN_20260328_22_30_34_ProWIN_20260328_22_30_33_Pro

In addition, I worked on the software, which is why
<small>(i'll add pictures next time if i remember)</small>
I have new software running that accurately uses gnss time and speed for display. It took me a while because half-way through, my computer glitched out, asked for 60 gigs of ram, and crashed in my face, taking with it some of my progress.

I have not only the speed (this time from gps, not just a placeholder), but I also have the time displaying and the battery percentage. The battery took me a bit because I had to find a way to decode the easy-to-read but not parse text from the cell chip. (The cell chip can measure battery voltage and percentage)

The time was its own headache because it just wouldn't sit right and like I had to find a way to change the timezone from utc. I installed a library that I couldn't figure out how to use, so my current setup is just the utc time, minus the offset, modded by 12. So, if its 0 o'clock utc, i'll get a negative number that will then mod back to a positive one, and all is well. It just can't handle dates at all, but hey, I only need to know the time, if that, while on a bike ride.

I will be prepping to submit this, even though the STM32 portion isn't really done, as the deadline is coming up way too fast.  

# 3/29/2026 - Over Discharged my LIIONS(to 2V) & software & testing  

_Time spent: 2.0h_  

I wrote some software and stuff to show the satellite information to see how many satellites are visible and connected. In addition, it also tells you, for each satellite, the signal-to-noise ratio, snr, and somehow I am getting ~49 outside, with high 40s for like 5 satellites, with a patch antenna. As if this isn't crazy enough, my HDOP is like ~1, and I am getting like ~35 near a window (inside) and like 30 near my monitors.

And yeah I left it to run a long test, and the battery really got over-discharged, as the buck-boost converter was still supplying my esp32 and screens with stable 3.3V. My Cell chip, however, was unhappy and shutdown. Since I was away, however, it went on for like either 2h10 ish or just 10 mins after the cell chip cut out at probably 2.5V.


<small>just some data: time, displaying percentage, %, actually percent, time stamp utc, pin value of the shutdown pin, newline, time it took to update LCD, check uarts, issue command for battery percentage, etc.</small>

I also did some tests outside, running around, going for a walk and all that, and I am happy to report it looks very accurate. I was getting, on the high side, about 22 km/h and like 5 km/h for my normal walk, which lines up with my estimates.  

# 3/30/2026 8 PM - PICS!!!! & Assembly  

_Time spent: 2.0h_  

I assembled like 10 screws to just have like the bare minimum structure, but I had to disassemble it before going somewhere (to turn it off) and well here it is!

WIN_20260330_20_11_05_ProWIN_20260328_22_30_38_ProWIN_20260328_22_29_52_ProWIN_20260328_22_30_34_ProWIN_20260330_20_10_35_Pro
WIN_20260330_20_11_16_ProWIN_20260328_22_30_33_ProWIN_20260328_22_30_29_Pro
WIN_20260330_20_14_40_ProWIN_20260330_20_14_14_Pro
WIN_20260330_20_15_52_Pro
WIN_20260330_20_15_54_ProWIN_20260330_20_15_48_Pro

And here is the bottom side with the clip-on and screw-on-able cover off. Notice that one battery clip is not soldered on because I forgot to include it in the BOM and like yeah.

WIN_20260330_20_18_08_ProWIN_20260330_20_17_33_ProWIN_20260330_20_17_57_ProWIN_20260330_20_18_00_ProWIN_20260330_20_18_04_ProWIN_20260330_20_17_52_ProWIN_20260330_20_17_49_ProWIN_20260330_20_17_54_Pro

Fully Assembled (minus the battery-clip) and the wires stuffed in.

WIN_20260330_20_20_43_ProWIN_20260330_20_20_37_ProWIN_20260330_20_20_34_ProWIN_20260330_20_20_31_ProWIN_20260330_20_20_41_Pro

I really need to make some cable-management slots in the new truss, but it pretty much works as is rn.

The battery-clip and stuff are a bit tight and hard to put together as I have to undo it all to turn it off, thus I don't have the pictures rn. It needs some software to fix that so that just hitting a button (which needs cutouts) will shut it down and power off the ESP32.  

# 3/30/2026 9 PM - Updated Bike Mount Part to Fit.  

_Time spent: 0.5h_  

Yep, that's exactly what I did. I extended the part, resized the holes to become perfect (hopefully) and I also made is so that it isn't the thick diameter all the way, just for a small area, which of course is filleted.



# 3/31/2026 - Got a 3D print, assembled, updated code  

_Time spent: 2.5h_  

ok well that was ... a bus ride

so basically, i had to go get a 3d print for my [#blueprint](https://hackclub.enterprise.slack.com/archives/C083S537USC) project, so I basically just went somewhere, and the thing is, I thought I started the print, but it didn't actually start, so when I came back to check on it an hour later, I saw it wasn't there. (It's a 30 minute print)

So, I asked the staff if they took out the part, but no, they couldn't find it. So, I'm like panicking, where did it go?????

We go to restart the print, and this time I sit there for a minute, and I see that the print doesn't start. We try different SD cards, and all that, still no progress. Then, we literally just restart the printer, and it all just works. 35 minutes later, I am running to the bus stop, in pouring rain. Like actually pouring rain

Like soooooo pourring that the water is bouncing like 5cm off of the grass

well that was how long it took to get the print and stuff, but well yeah that's life ig. (total unlogged (but journalled) time for print is now ~6 hrs)

Anyways, I also worked on the assembly, and I'm glad to say it works!





The screens are just flipped, but that's a simple 0 --> 2 change.

I also worked on getting the gps to work a bit faster, so now it's updating at 5hz, vs 1hz before. This way, it will feel more responsive. I was wondering why the command wasn't echoing, and apparently it must end in /r/n, and also apparently you need to tell it which pin is the tx pin. Huh, wouldn't have guessed.

Anyways, once I figured that out and got it to work, the satellite info was becoming fuzzy and changing too much so I made it only display the first 5 satellites (in order of signal strength) and I think all is well!

That assembly took a while as a component was a bit too big and thus flexed outwards so that the screw holes wouldn't align.  

# 4/3/2026 6 PM - Assembled/Tested [slight retro]  

_Time spent: 3.7h_  

Today was probably the nicest day this year, so far, and thus I took that opportunity to take it out for a bike ride. However, I had to assemble it first. There was mostly just the thing that I assembled it, but then I remembered that I had to flip the screen (in code) so I had to disassemble it to reprogram it. After re-assembling it, for some reason the GPS hung out, and thus I started to disassemble it. Lucky me, for some reason after just removing the first screw, it looked like it restarted, and started working.

However, this was the first sign of foreshadowing

I simply thought "Ooh, how lucky am I!" and continued on.

Once it was on there, I took it out for a bit, just down the street, and ... the wind! It was soooooooo windy. The advantage was, however, that on the way back I easily clocked (what my speedo says) around 32~34 km/h

The bike mount part looked a touch angled to me, however I just ignored it, thinking all would be well.

At some point, I was also thinking of what the biggest reason for it to fail would be. As I only had 3 screws on the bike mount (out of its designed 6) due to the mount flexing too much to fit the rest in, I thought that would be the biggest point. All other pieces bore relatively less weight, and were pretty sturdy, with several screws. The battery clip, for example, was mounted with 8 screws. (Believe me, it's a pain to put in on and take it off)

Anyways, I thought something along the lines of if a screw strips, I'll just take a look at it later. _Definitely_ not foreshadowing.

As all was going well, I went for a longer bike ride, a 15 km loop. And it was here where disaster struck.

I was about 500 meters in, where I noticed that there was quite a bit of a flex/offset on the bike-mount part, but I thought that it was probably just rotating, as perhaps the friction was a bit low.

I also suspected that the wind, which was easily gusting to ~50km/h was also perhaps to cause. Now that I think of it, maybe I should have paused to see if all was well, but uhhhh I was sort of stupid.

So, I started noticing that, at the 3km mark, the screen was wobbling enough that the battery clip (which's spring conducted so much power that it shorted together [this was when I accidentally shorted the antenna to the power pin]) was starting to give way at some times, resulting in the cell chip losing power without it shutting down. The datasheet clearly says not to do that as it might corrupt its software, and thus I thought of turning around. However, as I had already scaled the uphill and the upwind part, I didn't feel like undoing all my progress. I thought that I'll just go slower, feel less bumps, and continue on.

 #### I continued on to the 5~6 km mark, and disaster struck.

It was on a downhill, with the wind helping me, and even though I was trying to go slow I was probably clocking 20 to 25 km/h. And it was here that all three screws stripped. And the entire assembly, screens-first, fell onto the asphalt.

Thank goodness, however, it fell at a tiny bit of an angle so that the plastic absorbed some force, and the rest was on the screen with the screen protector on. Thus, after some cleaning, the screens look perfectly fine, but the main truss (that I was going to reprint for some issues anyways) has dirt on it and is a bit damaged.

Now, the painful part. I had to walk my bike for the 6km home, as the wind was gusting too hard for me to bike with a single hand. (I had to hold the odo in one, ofcourse)

Occasionally, I would take the risk and get on my bike, but everytime the wind became to powerful I would get back off.

Thankfully, after getting home, I was able to test it and confirm that all functions work.

 ### JOURNALLED TIME

As this included coming back home, I will **_NOT_** be logging that time, but the going there (testing) time and assembly is be logged. Journaling took 30 minutes. (I am not kidding I seriously write really detailed stuff.



Google maps shot of where it failed. I did not have my phone with me for the entirety of this ride.  

# 4/3/2026 7 PM - PROGRAMMED STM32  

_Time spent: 3.3h_  

So if you read my last journal, you'll know that I was having a bunch of trouble with the battery bouncing around and messing with the cell chip, and thus in the meantime I've worked on some code in the STM32CUBEIDE to allow me to basically short out a set of pins to shut down the ESP32, and another set to wake them up.

Basically, the wake up is quite simple, but the shutdown just signals the ESP32 to stop doing whatever it is, and then the ESP32 will shut down the cell chip. In turn, it will tell the STM32 that it's done, which will then cut off power to the ESP32.

I had a few problems where the STM32 would keep detecting a false low and turn on the ESP32, and even when it returns and tells it to turn off, it would flash off for like a millionth of a second, and then turn back on, a time period which was enough for just the capacitors to smooth out.

Anyways, I still have no idea why that happened, and my current work around is to just use a different pin. It could be that for some stupid reason I wired it up to two different IO pins on the STM32, and now I'm stuck with that pin not working. Thankfully, I designed so extra screw terminal blocks, so I will be (most likely) ok.

I also had a bit of a problem with me thinking that the terminal block was flipped around, so I shorted two IOs together, not an IO to ground. Simple fix, and all went well. (After like 10 minutes of debugging why its not working)

Anyways, I also had some timing off so that it would wake up, and the ESP32 wouldn't have a chance to tell the STM32 not to shut it back down, and the STM32 would do exactly that. Again, simple fix (long time to find) and I just added a bit of a delay.

I still don't have the touch/ina226/imu/mag wired up, but it all will be slow, and I will most likely just submit it up before that as I will have to find libraries and stuff.



I was thinking, I might just make it so that the same button will turn the ESP32 on or off. Hmmmmmmm. I think that might be a bit hard, but oh well.  

# 4/4/2026 - Failed to get ina226 to work even after spending ~7 hours  

_Time spent: 7.1h_  

Ok so basically, the tldr is that I tried to get libraries to work with the STM32 but couldn't understand it, so I tried getting the Arduino IDE to work again, it worked, but some very important pins like PC5 were not supported and thus I can use it either. Next steps are to either try getting my real board in the STM32 interface or building a simple custom library in STM32 HAL.


><small> No, I did **_not_** mean PC_5 </small>

Now the long story.

So, as I said, I wanted to get the other sensors/E-ink working.

That is basically all that remains to get the entire thing good, and functional.

First up, I tried the E-INK, as there supposedly is support for it to work. However, as it _is_ typical waveshare, so I can't understand anything.

Well, I did understand a bit. So it seems like its set up in having .h and .c files all together in a folder, but they keep pointing to each other so its quite hard to understand. Not to mention like _all_ the libraries are there, including those for like every single size they have ever made.

Well, that didn't work well, so now I decided to go and try the INA226 libraries. And, guess what. Not a single library I could find was recent, except [this one](https://github.com/macgeorge/STM32-example-codes/blob/master/6%20-%20INA226/F7_INA226.c) that is some 10 or 11 years old.

I guess I'll have to try that later, but if even the INA226 doesn't have one them I'm gonna be pretty surprised if the other sensors have them.

So, I sort of thought, what if I tried to get the thing working with the Arduino IDE.

And, believe it or not, it actually worked.

If you look at my journal a bunch of time ago, you will see that I said that I failed to do it. I still have the problem that the Arduino IDE doesn't officially support my board, but I was able to find a close board to that that allows me to toggle the first pin I tried, the LED pin.

So, with the Arduino IDE, I was able to actually program the board to flash an LED.

However, when I tried moving the program over, it didn't work the best. It gave me an error with pins PB12 (not too important) and PC5, the **_most_ important** pin. PC5 is the pin that toggles the ESP32's power.

Whereas my current board goes through the following phases:

[POWER ON/OFF SEQUENCE VIDEO](/user-attachments/blobs/proxy/eyJfcmFpbHMiOnsiZGF0YSI6MTMzNzU0LCJwdXIiOiJibG9iX2lkIn19--ae7d144141eb87a3c82ef218c9bc1c9791d14ded/WIN_20260404_19_04_11_Pro.mp4)

I _litterally wouldn't be able to turn the ESP32 on/off._

I had spent about an hour thirty at this point, and so I went off into google to find out if I can get that pin to work



btw, I had already had some trouble with the pins not mapping properly, so I had set up some programs to guess and check the pins to see which is which.

```  
for (int i=10; i<50; i++) {
    //Serial.println(i);
    pinMode(i, OUTPUT);
    digitalWrite(i, LOW);
  }

for (int i=30; i<37; i++) {
    Serial.println(i);
    pinMode(i, OUTPUT);
    digitalWrite(i, HIGH);
    delay(2000);
    digitalWrite(i, LOW);
    delay(1000);
  }
```

^^ this was my code to guess and check the PC5 pin. I went through all GPIOs that were close, and the ESP32 didn't get power :(

So, after that, I went around looking for the stuff. I found out that the problem was related to the Q port on the test board that I was using, and the options without the Q ending didn't have PC5 to begin with.

Basically, the Q port uses the pin mapped to PC5 normally as I think an SMPS pin, so it literally won't work. It only now makes sense why it wasn't working with that wide array of test pins.

If you look, the most frustrating part, is that the Arduino Core github repo actually has the STM32VGT folder, with the proper mappings for my board, but I can't select that from the Arduino IDE, and thus I can't use the Arduino IDE.

ofc, this took a lot longer than you would think, as like you _actually have to find out what is up_, including looking _understanding how c++ works **as a total beginner**_ (I have literally never used the Arduino IDE nor the C++ or C, except like one program for SOM)

So yeah this is where I've spent my last like 6~7 hours. It might not seem like that, but it really does take a long time.

And now what should I do next.

As I briefly touched upon in the TLDR, I really only have two options. Either figure out if I can get the correct board settings with the Arduino IDE, or build the custom libraries in the STM32 IDE. Both options are a real pain, but here are the pros for each:

|Arduino IDE|STM32CUBEMX|
|----|----|
|Simple to use if I can get it to work should not require me to re-write libraries for each of the (only) 3 sensors and the E-INK|Gives far more control and easier to optimise; can change the clock speed and other such stuff far easier|
|Simple to use, well supported|Certain to work, but a lot more work|
|Easier to program, included debugger so that I can actually have a working serial monitor to see what is going on| |

So, basically, the thing is do I want to have the chance of wasting my time in trying to get the Arduino IDE, while sacrificing performance, or do I just want to go for the STM32CUBEIDE, which will work for sure, but is definitely going to be a lot more work. Well I guess I have a lot to think of tonight.

As always, to make sure my journals are as detailed and engaging as possible I have invested a lot of time into it, with this journal taking me ~35 minutes. I _am_ logging this time.  

# 4/5/2026 3 PM - Made Code Simpler; Learned Booleans; Commented Code  

_Time spent: 0.4h_  

Yep. Did you know that C, natively, doesn't have booleans?

Well, quick fix, I just included `<stdbool.h>` and then it worked. Still really feels weird that it isn't the same color as the `int` or `void`s.

I needed this boolean, because I wanted to keep track of weather or not it has actually turned on or not, so that I can just use the same IO to both turn it on and off, as it now is. However, it really is a pain to understand what is happening (even if it is my own code) and thus I decided to comment it. Like pretty much every line has a comment. Take a look:



```
  while (1)
  {

	  // TURN OFF ESP32 - if ESP32 sends turn_off signal, turn it off.
	  if(HAL_GPIO_ReadPin(GPIOA, GPIO_PIN_10)) {
		  HAL_Delay(50); 														// Pause to see if it was accidental
		  if (HAL_GPIO_ReadPin(GPIOA, GPIO_PIN_10)) {							// Re-check to see if it is still on
			  HAL_GPIO_WritePin(GPIOC, GPIO_PIN_5, GPIO_PIN_RESET);				// Shut it off
			  HAL_GPIO_WritePin(GPIOE, GPIO_PIN_2, GPIO_PIN_RESET);				// Turn off LED
			  HAL_GPIO_WritePin(ESP_TX_GPIO_Port, ESP_TX_Pin, GPIO_PIN_RESET);	// Stop telling the ESP32 to shut off
			  esp_on = false;													// Register the ESP32 is now off
			  HAL_Delay(100);
		  }
	  }

	  // TURN ON/OFF ESP32
	  if(!HAL_GPIO_ReadPin(GPIOB, OFF_Pin)) {
		  if (!esp_on) {
			  HAL_GPIO_WritePin(GPIOC, GPIO_PIN_5, GPIO_PIN_SET);				// Turn on ESP32 Regulator
			  HAL_GPIO_WritePin(ESP_TX_GPIO_Port, ESP_TX_Pin, GPIO_PIN_RESET);	// Stop telling the ESP32 to shut off
			  HAL_Delay(1000);													// Wait for ESP32 to initialize, avoid turning it back off
			  esp_on = true;
		  } else {
			  // If ESP32 is on, send it the signal to turn off.
			  HAL_GPIO_WritePin(ESP_TX_GPIO_Port, ESP_TX_Pin, GPIO_PIN_SET);	// Send off signal to ESP32
			  HAL_GPIO_WritePin(GPIOE, GPIO_PIN_2, GPIO_PIN_SET);				// Turn on LED
		  }
	  }
```

Feels so profesional, doesn't it ^^

Next up, I'm going to rename all of those pins and stuff so that they actually make sense, and render my comments mostly useless.  

# 4/5/2026 9 PM - Further cleaned code; Added anti-theft tracking.  

_Time spent: 4.5h_  

Here's pretty much the same code as last time, but as you can see its cleaner

```
while (1)
  {

	  // TURN OFF ESP32 - if ESP32 sends turn_off signal, turn it off.
	  if(read_io(RX)) {
		  HAL_Delay(10); 							// Pause to see if it was accidental
		  if (read_io(RX)) {						// Re-check to see if it is still on
			  if (HAL_GetTick() < esp_on_ticks + 100) {
				  write_io(ESP_PWR, OFF);
				  HAL_Delay(10);
				  write_io(ESP_PWR, ON);
				  HAL_Delay(wake_pause);
				  esp_on_ticks = HAL_GetTick();
			  } else {
				  write_io(ESP_PWR, OFF);			// Shut it off
				  write_io(LED, OFF);				// Turn off LED
				  write_io(TX, OFF);				// Stop telling the ESP32 to shut off
				  write_io(ESP_UPDATE, OFF);
				  esp_on = false;					// Register the ESP32 is now off
				  HAL_Delay(10);
			  }
		  }
	  }

	  // TURN ON/OFF ESP32
	  if(!read_io(ON_OFF)) {
		  if (!esp_on) {
			  write_io(ESP_UPDATE, OFF);
			  write_io(ESP_PWR, ON);				// Turn on ESP32 Regulator
			  write_io(TX, OFF);					// Stop telling the ESP32 to shut off
			  HAL_Delay(wake_pause);				// Wait for ESP32 to initialize, avoid turning it back off
			  esp_on = true;
			  esp_on_ticks = HAL_GetTick();
		  } else {
			  // If ESP32 is on, send it the signal to turn off.
			  write_io(TX, ON);						// Send off signal to ESP32
			  write_io(LED, ON);					// Turn on LED
		  }
```

To do this, I (with like no knowledge of C) made two custom functions, one to read a pin and the other to write to a pin.



They do this by taking in an array to tell it which pin and then just writing to that pin. However, thanks to the `#define` command, I can just pass in a string (like RX or TX) and it will just parse it. Take a look at my above function for more clear stuff.

Ofcourse, I, mr python user, thought that C would have lists, but apparently they don't. Instead they use arrays, and as far as I can tell they can only have one type of thing in an array, so it basically can't work.

I need a `GPIO_TypeDef` object for the first one (the 'port') and a `uint16_t` (which i guess is just an integer) for the second one.

Thus, I had to make my own struct thingy or something. (This is one of the only parts made by AI)

```
typedef struct {
    GPIO_TypeDef *port;
    uint16_t pin;
} io;

// STATES
#define OFF 0
#define ON  1

// Pins
#define TX 			(io){GPIOA, TX_Pin}
#define RX 			(io){GPIOA, RX_Pin}
#define LED 		(io){GPIOE, GPIO_PIN_2}
#define ESP_PWR 	(io){GPIOC, GPIO_PIN_5}
#define ON_OFF		(io){GPIOB, IN2_Pin}
#define ESP_UPDATE	(io){GPIOA, GPIO_PIN_1}
#define wake_pause  1000
```

but hey, it works! so no complaint from me.

Anyways, after that I played around a bit with the clock, so basically now I know how to change the clock speed, and I configured it to use the external clock I put onto the board (its a 12MHz one, so CUBEMX had a touch of a problem)

Then, to save power, I reduced the clock way down to just 1MHz, which should be drawing just 20µA, but for some reason it isn't.

At 160MHz, it was drawing ~16 mA, so about 100µA per MHz, (5x more than datasheet), but this was before I added code to run with the timers, and maybe the external clock is also drawing power.

Speaking of which, you may have noticed that there was some code about restarting if I don't get a signal.

Sometimes, what happens is that the ESP32 fails to boot up, so if after about 1000 ms the STM32 is still getting a 'shut down' command, I'll know that it isn't working properly and I'll turn off and on the power on the ESP32 to reboot it. (This has happened quite a few times for some reason)

In doing so, I decided to tune the amount of time it waits, for whatever stupid reason, and just decided to consult GPT. It said that it takes about 50 µS for the code to run, so I started out with a wait of ~1 ms. The light just flickered, with power turning on and off rapidly, so I tried 50ms. After several tries I just decided to go to 2000ms (which worked) and now I have settled on 1000ms.

Just a reminder that changing code on the STM32 requires putting in to flash mode, connecting the programmer, building, and flashing, alongside actually testing it, which easily adds up.

After this, I worked on the anti-theft stuff, which took most of my time.

 ### Anti-Theft stuff

So, to track if it has been stolen, my plan is pretty simple. Every 10 or so minutes, wake it up, send the exact location to my MQTT broker, and tada. I can track exactly where the tracker is.

To do this, I had to like actually learn about timers (the above actually came afterwards, but hey this is more organizes)

Apparently, the STM32 has a bunch of timers that you can use, and I tried configuring one for my use, but it just wouldn't really work.

I googled my problem (again) and finally I was able to find out that the stm32 also has a function that will allow you to know how many seconds it has been since the code started executing, and you can just easily use that as a ms tracker.

Well, that is exactly what I did. At first, it was set to just be that the LED would (in a non-blocking way) turn on and off every 5 seconds, and after that success, I started building.

My STM32 code just ended up being quite simple, however my ESP32 code was far more complicated.

```
if (HAL_GetTick() % 600000 < 2000 && !esp_on) {
	write_io(ESP_PWR, ON);					// Turn on ESP32 Regulator
	write_io(TX, OFF);						// Stop telling the ESP32 to shut off
	write_io(ESP_UPDATE, ON);
	HAL_Delay(wake_pause);					// Wait for ESP32 to initialize, avoid turning it back off
	esp_on = true;
	esp_on_ticks = HAL_GetTick();
}
```

What that code just does is it turns it on, turns off the command io to shut down, turns on the 'express boot' io and then just waits for it to initialize.

In essence, my ESP32 code is just as simple as the following:

```
else:
    try:
        i = 0
        while i < 1000:
            while gnss.any():
                data = gnss.read()
                for byte in data:
                    stat = my_gps.update(chr(byte))
            sleep(0.01)
            i += 1
            if my_gps.satellites_in_use > 4:
                break
            
        sleep(0.5)
        send_message(f"{my_gps.latitude[0]}",  feed='latitude')
        send_message(f"{my_gps.longitude[0]}", feed='longitude')
        send_message(f"{my_gps.satellites_in_use}s {my_gps.speed[2]}km/h {my_gps.hdop} hdop {int(send_at('AT+CBC', show=False).split(',')[1])}%", feed='other_info')
        sleep(0.5)
    except Exception:
        sleep(2)
        power_off(False)

power_off(False)
```

However, to do this it required basically a complete restructuring of the code and also like _actually remembering how my code works._

There are also some other parts of my code, but this is the biggest part.

The biggest part was making sure that the GPS actually had a good set of data, and, at the very minimum, wasn't giving me 0s before sending the data.

While I was testing, I noticed that the ESP32 was reconnecting to Adafruit IO for some reason during every send, even if it was connected, at to figure out why I sort of fell into a rabbit hole.

It turns out, the problem was that my code for sending the info was lagging, and that was messing up the code that checks if the modem is connected.

I wish it were an easy fix to do that, but I had to like write my function to now check when the modem has returned the correct thing to then send the data after that, and then write the code, wait for the modem to get back, and then only continue with execution.

Well, for some reason that journal took _even longer than the rest._

It was ~40 minutes.

I'm probably missing something, but I really can't spend anymore time journaling — it's getting far too late.  

# 4/7/2026 10:04 PM - Filmed, Edited and Finished Demo  

_Time spent: 1.0h_  

 ### [DEMO!!!!](https://youtube.com/shorts/DLDQR-w_GeQ)

Yep, I think I got it done. Took me a bunch of time for me to assemble all ~30 screws, but hey, take a look ^^^

I even took the care to mute us out and replace it with some lovely music that isn't synced and definitely didn't take me just 10 minutes to put on there.

I sort of did have to like install DaVinci resolve, figure it out, and then like actually export it, so...



In addition, I also used up one of my three free monthly downloads for music (from upbeat) so there was also that.

(btw that was like my third shot, and I had to disassemble it all over again to be able to update the code.)  

# 4/7/2026 10:21 PM - Debugging Random Shutdowns.  

_Time spent: 1.5h_  

So the thing is, there is an off chance that my board might be like glitching, because Adafruit IO stopped receiving messages at 3 AM, for whatever reason. When I woke this morning, for some reason the ESP32 was still on, so I just rebooted the board. Since then it's worked just fine until now (10pm) and yeah.

In addition, there is also the problem that it once in a while it will turn on but not boot, and that's why I have some code on the STM32 to reboot the ESP32 if no code is running (it doesn't drive the comms pin high) within a second or two (like I mentioned before)



>code for it it isn't booting properly

```
	  if (esp_on && esp_on_ticks + 60000 < HAL_GetTick() && update) {
		  write_io(ESP_PWR, OFF);			// Shut it off
		  write_io(LED, ON);				// Turn on LED
		  write_io(ESP_UPDATE, ON);
		  HAL_Delay(1000);
		  write_io(ESP_PWR, ON);
		  HAL_Delay(wake_pause);
		  esp_on_ticks = HAL_GetTick();
	  }
```

I inturn added this tidbit so that if it's been over a minute with no return on the send messages function, then it will also reboot the ESP32, as per normal stuff, and if it returns too quickly or something it will reboot again.

Anyways, there is also a bit of code on the ESP32 side for that too, but that's just a simple log file, which is putting in numbers for some reason. I'll figure that out later.

```
    with open("log.txt", "a") as file:
        file.write(f"{machine.reset_cause()}\n")
```

Anyways, even after some serious code-look-over-ing, I still have no clue why it won't work. Ughhhh.

Maybe if the same issue happens again at 3AM or smth then I'll know, but the thing is that it will just eat it up and forget about it.

Hmmmm.

Also, my clock isn't accurate at all, and so it's actually like once every 9:45 or something, and thus like it just feels off. I'll have to find a fix for that too.

Anyways, for that last journal, you may have seen my thing about the free song download, and what happened is that I got a copyright notice, and so I panicked, but it was quite easy to fix.

Well, another thing, just as I'm journalling, this is the second time its woke up to transmit data.  

# 4/8/2026 9 PM - Failed To Get STM32 USB Working; INA226 Code  

_Time spent: 4.5h_  

Ok well today was pretty much a total failure, as I spent all my time trying to get the INA226 to work, for which I needed to have USB communication or something to actually get the data off.

So, first things first, I looked through the libraries and really there only is one that can work, and I tried copying things out of it. I copied the `#define`s and some really basic functions, just the read voltage and read shunt-voltage. However, it gave me the error that it couldn't find an I2C bus: I hadn't set it up, and that it couldn't find the `float32_t` typedef. This one really through me off, but as it turns out it's pretty much just the same as the normal `float`s. This one really took me a bit to understand as it really was weird.

Anyways, all that stuff was practically heaven compared to what came next.

Pretty much the worst (almost) **_three hours of my life_**

No matter what I did, there is literally nothing I can do to get the STM32 to just initialize its USB port, and just talk to me.

Apparently, I need to set up USB CDC, but the biggest thing is that they really stopped making it easy to use the old libraries, and now you have to use USBX, which I cannot, for the life of me, get to work. 

Firstly, it straight up wouldn't find the files. Kept giving me errors. I tried turning off USB and turning it back on, and for whatever mysterious reason it found them now. Well, one down.

Now, you have to turn on and download the `USB_DEVICE` middleware, but guess what? IT DOESN'T EXIST :(

bruuuuuuuuuuuuuuuuuuuuuuuuuuuuuuuuuuuuuuuuuuuuuuuuuuuuuuuuuuuuuuuuuuuuuuuuuuuuuuuuuuuuuuuuhhhhhhhhhhhhhhh

So now I'm stuck with USBX, something that I initialized, but have absolutely no clue how to use, after several hours spent on it.

Also it doesn't really leave me in the best mood after having spent my entire evening on a piece of code that lowered its ability and added the risk of maybe having destroyed something.

As a side note, I did upload all my stuff to github so there's at least that.



I'm not losing my code again. (Even if it still is quite simple)  

# 4/8/2026 10 PM - Gave GNSS More Time To Set Up  

_Time spent: 0.2h_  

I update my code to read:



This means that if it connects to 10 sats it will signal immediately, and for every 3 seconds that pass it will require one less satelite.

btw I also tested this ofc and everything.
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

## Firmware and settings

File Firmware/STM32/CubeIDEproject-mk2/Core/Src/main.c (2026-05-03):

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
/* Includes ------------------------------------------------------------------*/
#include "main.h"
#include "app_usbx_device.h"

/* USER CODE BEGIN Includes */
#include "stdbool.h"
#include "string.h"
#include "INA226.h"
#include "CSE_CST328.h"
#include "stdarg.h"
/* USER CODE END Includes */

/* USER CODE BEGIN PTD */
typedef struct {
    GPIO_TypeDef *port;
    uint16_t pin;
} io;
/* USER CODE END PTD */

/* USER CODE BEGIN PD */

// IO States
#define OFF 0
#define ON  1

// Pins
#define TX 			(io){GPIOA, TX_Pin}
#define RX 			(io){GPIOA, RX_Pin}
#define LED 		(io){GPIOE, GPIO_PIN_2}
#define ESP_PWR 	(io){GPIOC, GPIO_PIN_5}
#define INA_PWR		(io){GPIOE, GPIO_PIN_3}
#define ON_OFF		(io){GPIOB, IN2_Pin}
#define TP1_RST		(io){GPIOE, GPIO_PIN_15}

// Clock States
#define MHz48 1
#define lwPWR 2

// Others
#define wake_pause  1000

#define MAX(a, b) (((a) > (b)) ? (a) : (b))

/* USER CODE END PD */


I2C_HandleTypeDef hi2c1;
I2C_HandleTypeDef hi2c2;

SPI_HandleTypeDef hspi1;

PCD_HandleTypeDef hpcd_USB_OTG_FS;

/* USER CODE BEGIN PV */
bool esp_on = false;
uint32_t esp_on_ticks = 0;
uint8_t update = 0;
uint32_t last_printed_tick = 0;
uint8_t clock_state;
uint32_t last_update_tick;

// USB
#define BUFFER_SIZE 512
char buffer[BUFFER_SIZE];
uint32_t received = 0;
uint32_t sent = 0;

// Touch
CST328_HandleTypeDef touch;

// SPI
uint8_t tx_buf[5] = "HELLO";
uint8_t rx_buf[5];
/* USER CODE END PV */

void SystemClock_Config(void);
static void MX_GPIO_Init(void);
static void MX_ICACHE_Init(void);
static void MX_I2C1_Init(void);
static void MX_USB_OTG_FS_PCD_Init(void);
static void MX_SPI1_Init(void);
static void MX_I2C2_Init(void);
/* USER CODE BEGIN PFP */
void SystemClock_ConfigUSB(void);

void write_io(io pin, int state) {
	HAL_GPIO_WritePin(pin.port, pin.pin, state);
}

int read_io(io pin) {
	return HAL_GPIO_ReadPin(pin.port, pin.pin);
}

void print(char* text, ...) {
	ux_device_stack_tasks_run();
	char buffer[1024];
	va_list args;
	va_start(args, text);
	vsnprintf(buffer, sizeof(buffer), text, args);
	va_end(args);
	if (clock_state == lwPWR) {
		SystemClock_ConfigUSB();
	}
	int len = strlen(buffer);
	int offset = 0;
	while (offset < len) {
		int chunk_size = (len - offset > 8) ? 8 : (len - offset);
		USBD_CDC_ACM_Transmit((uint8_t*)buffer + offset, chunk_size, &sent);
		offset += chunk_size;
		ux_device_stack_tasks_run();
	}
	if (clock_state == lwPWR) {
		SystemClock_Config();
	}
}

int current_ua() {
	return INA226_getShuntV(&hi2c1, INA226_ADDRESS) * 50;
}

int current_ma() {
	return (int)(current_ua() / 1000);
}

int voltage_mv() {
	return (int)(INA226_getBusV(&hi2c1, INA226_ADDRESS));
}
/* USER CODE END PFP */

/**
  * @brief  The application entry point.
  * @retval int
  */
int main(void)
{

  /* MCU Configuration--------------------------------------------------------*/

  /* Reset of all peripherals, Initializes the Flash interface and the Systick. */
  HAL_Init();

  /* Configure the system clock */
  SystemClock_Config();

  /* USER CODE BEGIN SysInit */
  clock_state = lwPWR;
  /* USER CODE END SysInit */

  /* Initialize all configured peripherals */
  MX_GPIO_Init();
  MX_ICACHE_Init();
  MX_I2C1_Init();
  MX_USBX_Device_Init();
  MX_SPI1_Init();
  MX_I2C2_Init();
  /* USER CODE BEGIN 2 */
  INA226_setConfig(&hi2c1, INA226_ADDRESS, INA226_MODE_CONT_SHUNT_AND_BUS | INA226_VBUS_140uS | INA226_VBUS_140uS | INA226_AVG_1024);
  SystemClock_ConfigUSB();
  clock_state = MHz48;

  MX_USB_OTG_FS_PCD_Init();

  write_io(ESP_PWR, OFF);
  write_io(LED, OFF);
  write_io(INA_PWR, ON);
  write_io(TP1_RST, ON);

  CST328_InitHandle(&touch, &hi2c2, 240, 320);
  touch.rst_port = GPIOE;
  touch.rst_pin = GPIO_PIN_15;

  uint32_t start = HAL_GetTick();
  while (HAL_GetTick() < start + 1500) {
	  if (HAL_GetTick()%10 == 0 && last_printed_tick != HAL_GetTick()) {
		  sprintf((char*)buffer, "Current: %d\n", current_ua());
		  print(buffer);
		  last_printed_tick = HAL_GetTick();
	  }
  }

  //SystemClock_Config();
  //clock_state = lwPWR;
  write_io(INA_PWR, ON);

  last_update_tick = HAL_GetTick() - 295000;

  /* USER CODE END 2 */

  /* Infinite loop */
  /* USER CODE BEGIN WHILE */
  while (1) {
	  ux_device_stack_tasks_run();
	  if (esp_on && !update) {
		HAL_SPI_TransmitReceive(
			&hspi1,
			tx_buf,
			rx_buf,
			5,
			3
		);
	  }
	  if (esp_on) {
	      CST328_ReadData(&touch);
		  if (touch.touchPoints[0].state) {
			  print("X: %03d Y: %03d\n", touch.touchPoints[0].x, touch.touchPoints[0].y);
			  tx_buf[0] = 255;
			  tx_buf[1] = touch.touchPoints[0].x % 256;
			  tx_buf[2] = touch.touchPoints[0].x-256 > 255;
			  tx_buf[3] = touch.touchPoints[0].y % 256;
			  tx_buf[4] = touch.touchPoints[0].y > 255;
		  } else {
			  tx_buf[0] = 0;
		  }

	  }

	  if (HAL_GetTick() >= last_printed_tick + 500) {
		  print("Current: %d µA\nVoltage: %d mV\nTime Diff: %lums\n\n", current_ua(), voltage_mv(), HAL_GetTick() - last_printed_tick);
		  last_printed_tick += 500;
	  }
	  // TURN OFF ESP32 - if ESP32 sends turn_off signal, turn it off.
	  if(read_io(RX)) {
		  print("rxing\n");
		  HAL_Delay(10); 							// Pause to see if it was accidental
		  if (read_io(RX)) {						// Re-check to see if it is still on
			  if (HAL_GetTick() < esp_on_ticks + 100) {
				  write_io(ESP_PWR, OFF);
				  HAL_Delay(10);
				  write_io(ESP_PWR, ON);
				  HAL_Delay(wake_pause);
				  esp_on_ticks = HAL_GetTick();
			  } else {
				  write_io(ESP_PWR, OFF);			// Shut it off
				  write_io(LED, OFF);				// Turn off LED
				  write_io(TX, OFF);				// Stop telling the ESP32 to shut off
				  esp_on = false;					// Register the ESP32 is now off
				  HAL_Delay(10);
			  }
		  }
	  }

	  // TURN ON/OFF ESP32
	  if(!read_io(ON_OFF)) {
		  print("ON/OFF\n");
		  if (esp_on && update) {
			  write_io(ESP_PWR, OFF);
			  esp_on = false;
			  HAL_Delay(50);
		  }
		  if (!esp_on) {
			  write_io(ESP_PWR, ON);				// Turn on ESP32 Regulator
			  write_io(TX, OFF);					// Stop telling the ESP32 to shut off
			  HAL_Delay(wake_pause);				// Wait for ESP32 to initialize, avoid turning it back off
			  esp_on = true;
			  esp_on_ticks = HAL_GetTick();
			  update = 0;
			  for (uint16_t i = 0; i < 128; i++) {
			      if (HAL_I2C_IsDeviceReady(&hi2c2, (i << 1), 3, 5) == HAL_OK) {
			          print("Device found at 0x%02X\n", i);
			      }
			  }
		  } else {
			  // If ESP32 is on, send it the signal to turn off.
			  write_io(TX, ON);						// Send off signal to ESP32
			  write_io(LED, ON);					// Turn on LED
		  }
	  }

	  if (HAL_GetTick() > last_update_tick + 300000) {
		  if (!esp_on) {
			  print("LOGGING!\n");
			  write_io(ESP_PWR, ON);					// Turn on ESP32 Regulator
			  write_io(TX, ON);							// Tell ESP32 to Track
			  HAL_Delay(wake_pause);					// Wait for ESP32 to initialize, avoid turning it back off
			  esp_on = true;
			  esp_on_ticks = HAL_GetTick();
			  update = 1;
			  last_update_tick += 300000;
		  } else {
			  last_update_tick += 300000;
		  }
	  }

	  if (esp_on && esp_on_ticks + 90000 < HAL_GetTick() && update) {
		  print("ESP Update Timeout. Rebooting...\n");
		  write_io(ESP_PWR, OFF);				// Shut it off
		  write_io(LED, ON);					// Turn on LED
		  write_io(TX, ON);						// Tell ESP32 to Track
		  HAL_Delay(1000);
		  write_io(ESP_PWR, ON);
		  HAL_Delay(wake_pause);
		  esp_on_ticks = HAL_GetTick();
	  }

	  if (voltage_mv() < 3200) {
		  print("SHUTING DOWN: %d mV\n", voltage_mv());
		  write_io(LED, ON);					// Turn on LED

		  if (update) {
			  write_io(ESP_PWR, OFF);		// Turn of ESP32
			  write_io(TX, OFF);			// Stop Telling it to update/shut down
			  HAL_Delay(100);				// Wait for it to turn off
			  write_io(ESP_PWR, ON);		// Turn it on
			  HAL_Delay(wake_pause+5000);	// Pause for it to boot
		  }

		  // Enter standby
		  write_io(TX, ON);						// Send off signal to ESP32
		  write_io(INA_PWR, OFF);

		  HAL_Delay(15000);

		  write_io(ESP_PWR, OFF);
		  write_io(LED, OFF);
		  HAL_PWR_EnterSTANDBYMode();
		}
    /* USER CODE END WHILE */

    /* USER CODE BEGIN 3 */
  }
  /* USER CODE END 3 */
}

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
/* USER CODE BEGIN 4 */
void SystemClock_ConfigUSB(void)
{
  RCC_OscInitTypeDef RCC_OscInitStruct = {0};
  RCC_ClkInitTypeDef RCC_ClkInitStruct = {0};
  RCC_CRSInitTypeDef RCC_CRSInitStruct = {0};

  /** Configure the main internal regulator output voltage
  */
  if (HAL_PWREx_ControlVoltageScaling(PWR_REGULATOR_VOLTAGE_SCALE3) != HAL_OK)
  {
    Error_Handler();
  }

  /** Initializes the CPU, AHB and APB buses clocks
  */
  RCC_OscInitStruct.OscillatorType = RCC_OSCILLATORTYPE_HSI48|RCC_OSCILLATORTYPE_MSI;
  RCC_OscInitStruct.HSI48State = RCC_HSI48_ON;
  RCC_OscInitStruct.MSIState = RCC_MSI_ON;
  RCC_OscInitStruct.MSICalibrationValue = RCC_MSICALIBRATION_DEFAULT;
  RCC_OscInitStruct.MSIClockRange = RCC_MSIRANGE_0;
  RCC_OscInitStruct.PLL.PLLState = RCC_PLL_NONE;
  if (HAL_RCC_OscConfig(&RCC_OscInitStruct) != HAL_OK)
  {
    Error_Handler();
  }

  /** Initializes the CPU, AHB and APB buses clocks
  */
  RCC_ClkInitStruct.ClockType = RCC_CLOCKTYPE_HCLK|RCC_CLOCKTYPE_SYSCLK
                              |RCC_CLOCKTYPE_PCLK1|RCC_CLOCKTYPE_PCLK2
                              |RCC_CLOCKTYPE_PCLK3;
  RCC_ClkInitStruct.SYSCLKSource = RCC_SYSCLKSOURCE_MSI;
  RCC_ClkInitStruct.AHBCLKDivider = RCC_SYSCLK_DIV1;
  RCC_ClkInitStruct.APB1CLKDivider = RCC_HCLK_DIV1;
  RCC_ClkInitStruct.APB2CLKDivider = RCC_HCLK_DIV1;
  RCC_ClkInitStruct.APB3CLKDivider = RCC_HCLK_DIV1;

  if (HAL_RCC_ClockConfig(&RCC_ClkInitStruct, FLASH_LATENCY_1) != HAL_OK)
  {
    Error_Handler();
  }

  /** Enable the SYSCFG APB clock
  */
  __HAL_RCC_CRS_CLK_ENABLE();

  /** Configures CRS
  */
  RCC_CRSInitStruct.Prescaler = RCC_CRS_SYNC_DIV1;
  RCC_CRSInitStruct.Source = RCC_CRS_SYNC_SOURCE_USB;
  RCC_CRSInitStruct.Polarity = RCC_CRS_SYNC_POLARITY_RISING;
  RCC_CRSInitStruct.ReloadValue = __HAL_RCC_CRS_RELOADVALUE_CALCULATE(48000000,1000);
  RCC_CRSInitStruct.ErrorLimitValue = 34;
  RCC_CRSInitStruct.HSI48CalibrationValue = 32;

  HAL_RCCEx_CRSConfig(&RCC_CRSInitStruct);
}
/* USER CODE END 4 */
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


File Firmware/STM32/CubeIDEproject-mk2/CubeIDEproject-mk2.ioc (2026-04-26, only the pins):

Mcu.UserName=STM32U575VGTx
PA1.Signal=SPI1_SCK
PA10.GPIO_Label=RX
PA10.Signal=GPIO_Input
PA11.Signal=USB_OTG_FS_DM
PA12.Signal=USB_OTG_FS_DP
PA6.Signal=SPI1_MISO
PA7.Signal=SPI1_MOSI
PA9.GPIO_Label=TX
PA9.Signal=GPIO_Output
PB10.Signal=I2C2_SCL
PB12.GPIO_Label=IN2
PB12.Signal=GPIO_Input
PB14.Signal=I2C2_SDA
PB2.GPIO_Label=IN1
PB2.Signal=GPIO_Input
PB6.Signal=I2C1_SCL
PC4.GPIO_Label=SPI1_CS
PC4.Signal=GPIO_Input
PC5.GPIO_Label=ESP_PWR
PC5.Signal=GPIO_Output
PD8.GPIO_Label=TP1_INT
PD8.Signal=GPIO_Input
PE15.GPIO_Label=TP1_RST
PE15.Signal=GPIO_Output
PE2.GPIO_Label=LED
PE2.Signal=GPIO_Output
PE3.GPIO_Label=INA_PWR
PE3.Signal=GPIO_Output

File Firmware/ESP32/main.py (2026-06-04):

# Important Imports
from machine import Pin, UART, freq

# Prevent Automatic Shutdown / Comms
stm_com = Pin(43, Pin.OUT)
stm_com.off()

race_pin = Pin(6, Pin.IN, Pin.PULL_UP)
if not race_pin.value():
    import race
# Imports
from gps import GPS
from time import sleep_ms, ticks_ms, ticks_diff
import uasyncio as asyncio

from wifi import Wifi
from sim7080g import Cell
from mqtt import MQTT
from spi_comms import Comms

# Check if boot was for tracking or for 
track_pin = Pin(44, Pin.IN)
TRACK = True if track_pin.value() else False

# If running normally, import other things and initialize screen
if not TRACK:
    from screen import TFT, Button
    import gc
    
    tft = TFT()

# Simple swap-ins to help simplify typing
ms = "ms"

# initialize objects
cell = Cell()
gps = GPS()
wifi = Wifi()
mqtt = MQTT(cell, wifi)
comms = Comms()

# initialize IOs
shut_off_pin = Pin(0, Pin.IN, Pin.PULL_UP)
shut_off_pin2= Pin(44,Pin.IN, Pin.PULL_DOWN)


# -------------- Function Defines ---------------- #

# To shut everything down
def shut_down(asap):
    if cell.is_off and asap==False:
        sleep_ms(500)
    else:
        cell.off()
    stm_com.on()
    
async def check_if_i_want_to_shutdown(shut_down_button):
    await asyncio.sleep_ms(1000)
    if shut_down_button.is_pressed():
        tft.off()
        shut_down(True)
    
    
async def update_mqtt():
    cell_free = False
    # Connect to mqtt
    await cell.aon()
    
    # Get Battery Percentage
    btry = cell.btry
    
    for i in range(5):
        if btry == [1,1]:
            await asyncio.sleep_ms(5)
            btry = await cell.abtry()
        else:
            break
    
    # Updated screens
    if btry[0] < 30:
        tft.right.write(
            tft.font,
            f"{btry[0]:02d}%",
            160, 8,
            tft.red,
            tft.black
        )
    else:
        tft.right.write(
            tft.font,
            f"{btry[0]:02d}%",
            160, 8,
            tft.light_green,
            tft.black
        )
    
    if gps.lock:
        await mqtt.amsg(f'{gps.pos[1][0]} {gps.pos[1][1]} {gps.pos[0][0]} {gps.pos[0][1]} {gps.spd}', "trips", qos=0)
    
    await cell.aoff()
    cell_free = True

# ---------------- TRACKING CODE STARTS HERE ----------------- #
async def track():
    try:
        freq(80_000_000)
        st = ticks_ms()
        while ticks_ms() < 25_000 + st:
            gps.update(4096)
            if gps.sats[0] > 5:
                break
            print(gps.sats)
            sleep_ms(20)
        
        cell.on()
        wifi.on()
        
        while ticks_ms() < 40_000 + st:
            sleep_ms(20)
            gps.update(4096)
            if gps.lock:
                break
        
        gps.ban_updates()
        bat_list = cell.at('CBC').split(',')
        if gps.lock:
            gps.off()
            
            await mqtt.amsg(
                f"{gps.pos[1][0]}",
                "latitude"
            )
            
            cell_offing = False
            if wifi.is_connected_to_wifi:
                print("turning off")
                cell_offing = True
                cell_off_func = asyncio.create_task(cell.aoff())
                
            await mqtt.amsg(
                f"{gps.pos[0][0]}",
                "longitude"
            )
            
            await mqtt.amsg(
                f"{"/".join(map(str, gps.sats))}s {round(gps.speed, 2)}km/h {gps.gps.hdop} hdop {bat_list[1]}% ({bat_list[2][:-8]}mV) waited: {(ticks_ms()-st)//1000}s",
                feed='other-info'
            )
            if cell_offing:
                while not cell_off_func.done():
                    await asyncio.sleep_ms(10)
        else:
            cell.send_message(f"NO LOCK: {"/".join(map(str, gps.sats))}s {gps.gps.hdop} hdop {bat_list[1]}% ({bat_list[2][:-8]}mV) waited: {(ticks_ms()-st)//1000}s", feed='other-info')
    except Exception as e:
        print(e)
        shut_down(True)
    except KeyboardInterrupt:
        return
    shut_down(True)
    
# -------------------- MAIN LOOP STARTS HERE -------------------- #
async def main():
    # Track if requested
    if TRACK:
        await track()
        return 1
    # Max out speed
    freq(240_000_000)
    
    # Set up screens
    tft.fill_all(tft.black)
    
    tft.left.write(
        tft.big_font,
        b'KM/H',
        10, 200,
        tft.white,
        tft.black)
    
    # Starting Variables
    old_speed = 978
    last_gc_collect = 0
    last_cell_on = ticks_ms()-42_000
    sat_string = ''
    cell_free = True
    
    last_one_sec_time = 0
    
        # for stopwatch
    stop_watch_time = 0
    stop_watch_offset = 0
    stop_watch_running = False
    
    # Clear GPS Buffer
    gps.uart.read()
    
    # Start background asyncronous touch updater
    asyncio.create_task(comms.background_touch_updater())
    
    # Buttons
    shut_down_button = Button(tft.right, 20, 240, 200, 60, tft.red, comms)
    gc_collect_button = Button(tft.right, 145, 85, 75, 25, tft.light_green, comms)
    
    start_stopwatch_button = Button(tft.right, 35, 180, 75, 35, tft.light_green, comms)
    stop_stopwatch_button = Button(tft.right, 125, 180, 75, 35, tft.red, comms)
    
    # Run loop
    while True:
        # Update GPS Values
        gps.update()
        
        # await to give the async functions a chance
        await asyncio.sleep_ms(1)
        
        # Check if it has been 45 seconds, and if so update the mqtt servers
        if last_cell_on + 45_000 < ticks_ms():
            last_cell_on = ticks_ms()
            if cell_free: # Ensure cell isn't alread on
                asyncio.create_task(update_mqtt())
                
        # await to give the async functions a chance
        await asyncio.sleep_ms(1)
        
        # Check if shutdown signal is given
        if not shut_off_pin.value() or shut_off_pin2.value():
            shut_down(True)
            
        # Collect GC if it is getting full
        if ticks_ms() > last_gc_collect + 600_000:
            print("COLLECTING GARBAGE")
            gc.collect()
            last_gc_collect = ticks_ms()
            
            # await to give the async functions a chance
            await asyncio.sleep_ms(1)
            
        
        # Update screens if there is new GPS information
        if gps.new:
            
            # Don't let GPS values change while updating screens
            gps.ban_updates()
            
            # Get starting time to monitor time taken to update
            s_t = ticks_ms()
            
            # Add main speed
            if round(old_speed) != round(gps.spd):
                tft.left.write(
                    tft.speed_font,
                    f"{round(gps.spd):02d}",
                    5, 30,
                    tft.white,
                    tft.black
                )
                
            # await to give the async functions a chance
            await asyncio.sleep_ms(1)
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

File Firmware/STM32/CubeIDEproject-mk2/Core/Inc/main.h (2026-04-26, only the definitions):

#define LED_Pin GPIO_PIN_2
#define LED_GPIO_Port GPIOE
#define INA_PWR_Pin GPIO_PIN_3
#define INA_PWR_GPIO_Port GPIOE
#define SPI1_CS_Pin GPIO_PIN_4
#define SPI1_CS_GPIO_Port GPIOC
#define ESP_PWR_Pin GPIO_PIN_5
#define ESP_PWR_GPIO_Port GPIOC
#define IN1_Pin GPIO_PIN_2
#define IN1_GPIO_Port GPIOB
#define TP1_RST_Pin GPIO_PIN_15
#define TP1_RST_GPIO_Port GPIOE
#define IN2_Pin GPIO_PIN_12
#define IN2_GPIO_Port GPIOB
#define TP1_INT_Pin GPIO_PIN_8
#define TP1_INT_GPIO_Port GPIOD
#define TX_Pin GPIO_PIN_9
#define TX_GPIO_Port GPIOA
#define RX_Pin GPIO_PIN_10
#define RX_GPIO_Port GPIOA

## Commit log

2026-01-27 Update and rename Cpeedo Mk5 BOM - Sheet1.csv to BOM.csv
    [BOM.csv]
2026-01-27 Update BOM.csv
    Made it a touch clearer
    [BOM.csv]
2026-01-27 Added source CAD
    [Cpeedo-mk5.f3z, Cpeedo-mk5.step]
2026-01-27 Organized, Added ESP32 Firmware
2026-02-11 Added Schematic
2026-03-07 Updated Files To Latest Version
    [PCB-BOM_Cpeedo-mk5.csv, PickAndPlace_Cpeedo-mk5.csv]
2026-03-22 Added STL Files
    [Battery.stl, Bike-Mount.stl, Cpeedo-mk5.f3z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]
2026-03-27 Update Main Truss.stl
    [Main Truss.stl]
2026-03-31 Update README.md
    Added new photos of actual board
2026-03-31 Updated ESP32 Firmware
2026-04-09 V1 STM32 Wake-Up
2026-04-10 Updated STM32 Software
2026-04-11 Added my working STM32CUBEIDE Directory
2026-04-11 Added LED for debugging
2026-04-12 Update code; Added print function
2026-04-12 Update USB Code
    Code now sends data on whether the ESP32 is on.
2026-04-19 Updated ESP32 Firmware and Enable STM32 Power Logging
2026-04-19 Updated STM32 and ESP32 Firmware
2026-04-19 Updated Battery Clip and Bike Mount STLs
    Basically the V1 setup was far too weak, and thus I've added more space on the clip for the threads to hold onto.
    [Battery.stl, Bike-Mount.stl]
2026-04-24 Updated STM32 Firmware
2026-04-24 Updated Emergency Shutdown Code
    Increased delay to prevent ESP32 from tracking.
    [main.c]
2026-04-26 Added Preliminary Touch and SPI communication capabilities.
2026-04-28 Rushed up buggy wifi logging.
    [main.py, wifi.py]
2026-04-28 Cleaned up still very buggy main.py wifi + cell combo logging
    [main.py]
2026-05-03 Updated ESP32 Code to use new MQTT Library.
2026-05-03 Updated STM32 Code
    This new code can now force an updating ESP32 to now run normally, and also gives 90 seconds to the ESP32 to update the web servers.
2026-05-12 Cleaned up prints
2026-05-30 Add entry about dead batteries and voltage issue
    Documented an issue with battery voltage dropping unexpectedly.
2026-05-30 Update JOURNAL.md with recent project developments
    Documented progress on touch display implementation and issues encountered with ESP32 performance.
2026-05-30 Insert webcam image in JOURNAL.md
    Added a webcam image to the journal entry.
2026-06-01 Add entry for shutdown button implementation
    Documented the implementation of a shutdown button with its functionality and debugging process.
2026-06-01 Document low power LCD research and setup
    Added a new entry about low power LCD setup and research.
2026-06-02 Update journal with project completion details
    Documented the completion of the project with details on assembly, functionality, and future improvements. Added images and reflections on the experience.
2026-06-03 Update Bike-Mount STL
    Replace CAD/Bike-Mount.stl with an updated binary model.
    [Bike-Mount.stl]

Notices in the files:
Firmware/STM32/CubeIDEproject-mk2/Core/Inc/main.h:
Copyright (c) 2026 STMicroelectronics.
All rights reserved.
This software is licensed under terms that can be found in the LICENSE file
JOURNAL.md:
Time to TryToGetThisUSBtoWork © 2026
